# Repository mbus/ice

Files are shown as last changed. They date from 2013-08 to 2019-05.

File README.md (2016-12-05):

ICE EVM Board
=============

The ICE (In-Circuit Emulation) Evaluation Module is a debug board built for the
M3 ecosystem. In addition to acting as an M3 EVM, the ICE board can act as an
MBus debugger. ICE can act as a passive monitor, member node, or bus master as
desired.

ICE uses a [custom serial protocol][protocol] to communicate with a host PC.
There is a [Python library][py-ice] that provides a reasonably high-level API
to ICE and MBus.

This repository hosts the hardware and firmeware for ICE.

For more information, please visit http://mbus.io/ice.html

[protocol]: http://mbus.io/static/ICE-Protocol.pdf
[py-ice]: https://github.com/mbus/m3-python

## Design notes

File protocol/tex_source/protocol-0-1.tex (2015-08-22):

\subsection{Version 0.1}
\label{protocol-0-1}

\setcounter{tocdepth}{4}
\etocsettocstyle
    {\subsection*{\contentsname}\hrule\medskip
        \everypar{\rightskip.1\linewidth}}
    {\nobreak\medskip\hrule\bigskip}

\localtableofcontents

\subsubsection{\texttt{0x64 `d'} -- Discrete interface I2C message}
{\em Synchronous Request, Asynchronous Message}
\begin{itemize}
  \item[]
    \begin{bytefield}{40}
      \colorbitbox{lightgreen}{8}{`d'} &
      \colorbitbox{lightred}{8}{Event ID} &
      \colorbitbox{lightcyan}{8}{Length} &
      \bitbox{4}{Data...}
    \end{bytefield}
  \item The bytes in this message compose an I2C transaction.
  \item The length field of this message necessarily limits the maximum
    message size to 255 bytes (addr + 254 data). Longer messages should
    be fragmented.
  \item The sentinel value {\tt 255} for length indicates a {\em
    fragmented} message.
  \item[]
    \begin{itemize}
      \item A message fragment {\bf MUST} be exactly 255 bytes long.
      \item A fragment message {\bf MUST} be followed by another
        fragment, or terminated by a regular {\bf d}iscrete message.
        \begin{itemize}
          \item The ICE board is permitted to interleave other,
            non-I2C related messages (e.g. GPIO events).
        \end{itemize}
      \item A series of message fragments {\bf MUST} always be
        terminated by a discrete with an explicit length. An I2C transaction of
        length 0 is permitted, e.g.:
        \begin{itemize}
          \item An I2C transaction of length 510 (1 byte addr + 509 bytes
            of data) would be {\bf three} messages. The first of length
            255 (addr + bytes 0-253), the second of length 255 (bytes
            254-508), and the third of length 0 (there is no more
            data, but the fragment series must be terminated).
        \end{itemize}
      \item Fragments are treated as one logical message, but individual I2C bus
        transactions, by an ICE board.  In practice this means:
        \begin{itemize}
          \item Each fragment message must be individually ACK'd by ICE.
            \begin{itemize}
              \item A NAK'd fragment message ends an I2C message.
              \item The NAK offset is relative to the current fragment, not
                the whole I2C transaction.
            \end{itemize}
          \item Only the first fragment includes the I2C address.
          \item A stop bit should {\bf NOT} be generated after a
            fragment, instead the I2C clock should be stretched until the
            next fragment has arrived.
        \end{itemize}
    \end{itemize}
  \item ICE will respond with an ACK once every byte from an individual `d'
    message has been ACK'd on the I2C bus.
  \item If a byte is NAK'd on the I2C bus, ICE will respond with a NAK message
    of length 1 indicating the index of the first NAK'd byte (e.g. if the
    address is NAK'd, it will return 0).
    \begin{itemize}
      \item[]
        \begin{bytefield}{32}
          \colorbitbox{lightgreen}{8}{NAK (0x01)} &
          \colorbitbox{lightred}{8}{Event ID} &
          \colorbitbox{lightcyan}{8}{Len (Must be 1)} &
          \bitbox{8}{Index of Byte NAK'd}
        \end{bytefield}
    \end{itemize}
\end{itemize}

\subsubsection{\texttt{0x49 `I'} -- Query I2C Configuration}
{\em Synchronous Request}
\begin{itemize}
  \item[]
    \begin{bytefield} \\
      \colorbitbox{lightgreen}{8}{0x49} &
      \colorbitbox{lightred}{8}{Event ID} &
      \colorbitbox{lightcyan}{8}{Len (Must be 1)} &
      \colorbitbox{lightergreen}{8}{Parameter} &
    \end{bytefield}
  \item These messages complement the set I2C messages.
  \item The `Parameter' field is the parameter specifier to query.
  \item An ACK response should mimic the corresponding set message.
  \item The following would query/response the address mask:
    \begin{quote}
      \begin{bytefield} \\
        \colorbitbox{lightgreen}{8}{0x49} &
        \colorbitbox{lightred}{8}{Event ID} &
        \colorbitbox{lightcyan}{8}{0x01} &
        \colorbitbox{lightergreen}{8}{0x61} &
      \end{bytefield}

      \begin{bytefield} \\
        \colorbitbox{lightgreen}{8}{ACK (0x00)} &
        \colorbitbox{lightred}{8}{Event ID} &
        \colorbitbox{lightcyan}{8}{0x02} &
        \bitbox{8}{Ones Mask} &
        \bitbox{8}{Zeros Mask} &
      \end{bytefield}
    \end{quote}
\end{itemize}

\subsubsection{\texttt{0x69 `i'} -- Set I2C Configuration}
{\em Synchronous Request}
\begin{itemize}
  \item The first byte of the message shall define which parameter is to
    be configured.

  \paragraph{\texttt{0x69 0x63 `ic'} -- Set I2C Clock Speed}
    \begin{itemize}
      \item[]
        \begin{bytefield} \\
          \colorbitbox{lightgreen}{8}{`i'} &
          \colorbitbox{lightred}{8}{Event ID} &
          \colorbitbox{lightcyan}{8}{Len (Must be 2)} &
          \colorbitbox{lightergreen}{8}{`c'} &
          \bitbox{8}{Clock Speed}
        \end{bytefield}
      \item {\bf Default:} {\tt 0x32} (50, 100~kHz)
      \item This shall be followed by a single byte
        valued N, where N~*~2~kHz yeilds the desired clock speed. Values of N
        greater than 200 (400~kHz) exceed the I2C spec and may be rejected.
    \end{itemize}
  \paragraph{\texttt{0x69 0x61 `ia'} -- Set ICE I2C Address}
    \begin{itemize}
      \item[]
        \begin{bytefield} \\
          \colorbitbox{lightgreen}{8}{`i'} &
          \colorbitbox{lightred}{8}{Event ID} &
          \colorbitbox{lightcyan}{8}{Len (Must be 3)} &
          \colorbitbox{lightergreen}{8}{`a'} &
          \bitbox{8}{Ones Mask} &
          \bitbox{8}{Zeros Mask}
        \end{bytefield}
      \item {\bf Default:} {\tt 0xff 0xff} (disabled)
      \item This shall be followed by two bytes,
        first the {\em ones mask} and then the {\em zeroes mask} as outlined below.
        The command sets the address mask that ICE board should pretend to be a device
        for. Coneceptually the mask is of the form {\tt 10xx010x}, where x's signify
        don't care. This is conveyed as a {\em ones mask} and a {\em zeroes mask},
        where each mask defines the bits that must be a one or zero respectively. For
        the given example, the ones mask would be {\tt 10000100} and the zeroes mask
        {\tt 01001010}, generating a transaction of \mbox{\tt 0x61 0x84 0x4a}.
      \item To disable address-faking, set any bit
        as both required-one and required-zero. This impossible situation is a legal
        setting that will never match.
        \begin{itemize}
          \item {\em Note:} While it is
            permissable to set the last bit must-be-zero (writeable-only) or must-be-one
            (readable-only), it is almost certainly an error to do so.
        \end{itemize}
    \end{itemize}
  \paragraph{\texttt{0x69} Responses}
    \begin{itemize}
      \item NAKs for this message shall be composed of an error
        code, followed by an optional explanitory string.
        \begin{itemize}
          \item[]
            \begin{bytefield} \\
              \colorbitbox{lightgreen}{8}{NAK (0x01)} &
              \colorbitbox{lightred}{8}{Event ID} &
              \colorbitbox{lightcyan}{8}{Len (Min: 1)} &
              \colorbitbox{lightblue}{8}{EINVAL (0x16)} &
              \bitbox{8}{[{\tt "Out of Range"}]} &
            \end{bytefield}
          \item {\texttt {\textbf EINVAL (22,0x16):}} Invalid argument.
          \item[]
            \begin{bytefield} \\
              \colorbitbox{lightgreen}{8}{NAK (0x01)} &
              \colorbitbox{lightred}{8}{Event ID} &
              \colorbitbox{lightcyan}{8}{Len (Min: 1)} &
              \colorbitbox{lightblue}{8}{ENODEV (0x13)} &
            \end{bytefield}
          \item {\texttt {\textbf ENODEV (19,0x13):}} The
            implementation does not support changing or querying this parameter. Unless
            otherwise specified, it {\bf MUST} be hardcoded to the default.
        \end{itemize}
    \end{itemize}
\end{itemize}

\subsubsection{\texttt{0x66 `f'} -- FLOW (GOC) interface message}
{\em Synchronous Request}
\begin{itemize}
  \item FLOW messages are formatted the exact same as `d'iscrete messages.
\end{itemize}

\subsubsection{\texttt{0x4f `O'} -- Query optical (FLOW (GOC)) Configuration}
{\em Synchronous Request}
\begin{itemize}
  \item[]
    \begin{bytefield} \\
      \colorbitbox{lightgreen}{8}{`O' (0x4f)} &
      \colorbitbox{lightred}{8}{Event ID} &
      \colorbitbox{lightcyan}{8}{Len (Must be 1)} &
      \colorbitbox{lightergreen}{8}{Parameter} &
    \end{bytefield}
  \item These messages complement the set I2C messages.
  \item The `Parameter' field is the parameter specifier to query.
  \item An ACK response should mimic the corresponding set message.
\end{itemize}

\subsubsection{\texttt{0x6f `o'} -- Set optical (FLOW (GOC)) Configuration}
{\em Synchronous Request}
\begin{itemize}
  \item The first byte of the message shall define which parameter is to
    be configured.
    \paragraph{\texttt{0x6f 0x63 `oc'}: Clock Speed (Divider)}
      \begin{itemize}
        \item[]
          \begin{bytefield} \\
            \colorbitbox{lightgreen}{8}{`o'} &
            \colorbitbox{lightred}{8}{Event ID} &
            \colorbitbox{lightcyan}{8}{Len (Must be 4)} &
            \colorbitbox{lightergreen}{8}{`c'} &
            \bitbox{8}{Clock Divider}
          \end{bytefield}
        \item {\bf Default:} {\tt 0x30D400} (2~MHz / 0x30D400 = .625~Hz)
        \item This shall be followed by a three byte
          value N (MSB-first), where 2~MHz / N yields the desired clock speed.
      \end{itemize}
  \paragraph{\texttt{0x6f} Responses}
    \begin{itemize}
      \item NAKs for this message shall be composed of an error
        code, followed by an optional explanitory string.
        \begin{itemize}
          \item[]
            \begin{bytefield} \\
              \colorbitbox{lightgreen}{8}{NAK (0x01)} &
              \colorbitbox{lightred}{8}{Event ID} &
              \colorbitbox{lightcyan}{8}{Len (Min: 1)} &
              \colorbitbox{lightblue}{8}{EINVAL (0x16)} &
              \bitbox{8}{[{\tt "Out of Range"}]} &
            \end{bytefield}
          \item {\texttt {\textbf EINVAL (22,0x16):}} Invalid argument.
        \end{itemize}
    \end{itemize}
\end{itemize}

\subsubsection{\texttt{0x47 `G'} -- Query GPIO State / Configuration}
{\em Synchronous Request}
\begin{itemize}
  \item[]
    \begin{bytefield} \\
      \colorbitbox{lightgreen}{8}{`G' (0x47)} &
      \colorbitbox{lightred}{8}{Event ID} &
      \colorbitbox{lightcyan}{8}{Len (Must be 2)} &
      \colorbitbox{lightergreen}{8}{Parameter} &
      \bitbox{8}{GPIO IDX}
    \end{bytefield}
  \item These messages complement the set GPIO (`g') messages.
  \item The `Parameter' field is the parameter specifier to query.
  \item An ACK response should mimic the corresponding set message.
\end{itemize}

\subsubsection{\texttt{0x67 `g'} -- Set / Configure GPIO}
{\em Synchronous Request, Asynchronous Message}
\begin{itemize}
  \item The first byte of this message shall be a specificer, indicating
    what type of GPIO action is requested.
  \paragraph{\texttt{0x67 0x6c `gl'} -- GPIO Level}
    \begin{itemize}
      \item The first byte of the message shall be an integer
        indicating the GPIO index to set. The second byte shall be
        valued {\tt 0} or {\tt 1}, depending on the desired GPIO
        state.
      \item[]
        \begin{bytefield} \\
          \colorbitbox{lightgreen}{8}{`o' (0x67)} &
          \colorbitbox{lightred}{8}{Event ID} &
          \colorbitbox{lightcyan}{8}{Len (Must be 3)} &
          \colorbitbox{lightergreen}{8}{`l' (0x6c)} &
          \bitbox{8}{GPIO IDX} &
          \bitbox{8}{GPIO Val}
        \end{bytefield}
    \end{itemize}
  \paragraph{\texttt{0x67 0x64 `gd'} -- GPIO direction}
    \begin{itemize}
      \item The first byte of the message shall be an integer
        indicating the GPIO index to set the direction of. The second
        byte shall be valued:
        \begin{itemize}
          \item 0: Input
          \item 1: Output
          \item 2: TriState (\textsc{DEFAULT})
        \end{itemize}
      \item[]
        \begin{bytefield} \\
          \colorbitbox{lightgreen}{8}{`o' (0x67)} &
          \colorbitbox{lightred}{8}{Event ID} &
          \colorbitbox{lightcyan}{8}{Len (Must be 3))} &
          \colorbitbox{lightergreen}{8}{`d' (0x64)} &
          \bitbox{8}{GPIO IDX} &
          \bitbox{8}{GPIO Direction}
        \end{bytefield}
    \end{itemize}
  \paragraph{\texttt{0x67} Responses}
    \begin{itemize}
      \item {\texttt {\textbf ENODEV (19,0x13):}} The requested
        GPIO does not exist.
      \item[]
        \begin{bytefield} \\
          \colorbitbox{lightgreen}{8}{NAK (0x01)} &
          \colorbitbox{lightred}{8}{Event ID} &
          \colorbitbox{lightcyan}{8}{Len (Min: 1)} &
          \colorbitbox{lightblue}{8}{ENODEV (0x13)} &
          \bitbox{8}{[{\tt "No such GPIO"}]} &
        \end{bytefield}
      \item {\texttt {\textbf EINVAL (22,0x16):}} The requested GPIO
        exists, but cannot be configured this way at this time.
      \item[]
        \begin{bytefield} \\
          \colorbitbox{lightgreen}{8}{NAK (0x01)} &
          \colorbitbox{lightred}{8}{Event ID} &
          \colorbitbox{lightcyan}{8}{Len (Min: 1)} &
          \colorbitbox{lightblue}{8}{EINVAL (0x16)} &
          \bitbox{8}{[{\tt "GPIO is input"}]} &
        \end{bytefield}
    \end{itemize}
\end{itemize}

\subsubsection{\texttt{0x50 `P'} -- Query Power State}
{\em Synchronous Request}
\begin{itemize}
  \item[]
    \begin{bytefield} \\
      \colorbitbox{lightgreen}{8}{`P' (0x50)} &
      \colorbitbox{lightred}{8}{Event ID} &
      \colorbitbox{lightcyan}{8}{Len (Must be 1)} &
      \colorbitbox{lightergreen}{8}{Parameter} &
      \bitbox{8}{PWR IDX}
    \end{bytefield}
  \item These messages complement the Set Power (`p') messages.
  \item The `Parameter' field is the parameter specifier to query.
  \item An ACK response should mimic the corresponding set message.
\end{itemize}

\subsubsection{\texttt{0x70 `p'} -- Set Power State}
{\em Synchronous Request, Asynchronous Message}
\begin{itemize}
  \item Set Power State messages allow direct control of set-point voltage and on/off states for various power domains on the ICE board.  The first byte of this message shall be a specificer, indicating which parameter is requested.  The second byte of the message shall be the power domain identifier.  Currently implemented power domain identifiers are:
   \begin{itemize}
     \item 0: M3 0.6V (0.675V Default)
     \item 1: M3 1.2V (1.2V Default)
     \item 2: M3 VBatt (3.8V Default)
   \end{itemize}
  \paragraph{\texttt{0x70 0x76 `pv'} -- Voltage State}
    \begin{itemize}
      \item The first byte of the message shall be a single byte indicating the power domain identifier to set.  The second byte ($v\_set$) shall specify the voltage according to the equation:
$$V_{out} = (0.537 + 0.0185*v\_set)*V_{default}$$
      Valid values for $v\_set$ range from {\tt 0} to {\tt 31}
      \item[]
        \begin{bytefield} \\
          \colorbitbox{lightgreen}{8}{`p' (0x70)} &
          \colorbitbox{lightred}{8}{Event ID} &
          \colorbitbox{lightcyan}{8}{Len (Must be 3)} &
          \colorbitbox{lightergreen}{8}{`v' (0x76)} &
          \bitbox{8}{PWR IDX} &
          \bitbox{8}{$v\_set$}
        \end{bytefield}
    \end{itemize}
  \paragraph{\texttt{0x70 0x6f `po'} -- On/Off State}
    \begin{itemize}
      \item The first byte of the message shall be a single byte indicating the power domain identifier to set.  The second byte shall be
        valued {\tt 0} or {\tt 1}, depending on the desired On/Off
        state.
      \item[]
        \begin{bytefield} \\
          \colorbitbox{lightgreen}{8}{`p' (0x70)} &
          \colorbitbox{lightred}{8}{Event ID} &
          \colorbitbox{lightcyan}{8}{Len (Must be 3)} &
          \colorbitbox{lightergreen}{8}{`o' (0x6f)} &
          \bitbox{8}{PWR IDX} &
          \bitbox{8}{On/Off}
        \end{bytefield}
    \end{itemize}
\end{itemize}

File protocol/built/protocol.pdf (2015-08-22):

# ICE Debug Board FPGA Interface protocol

Ben Kempke, Pat Pannuto {bpkempke,ppannuto}@umich.edu

Revision 0.2.6 — October 17, 2013

## Introduction

The ICE board is a dual-purpose development board, enabling both high-speed programming (via DMA) of M3 chips and interfacing with live M3 sessions and external peripherals.
This means that libraries must be able to gracefully handle asychronous, unexpected events. In particular, some semantics resemebling transactions would be desirable, as well as an effort to maintain event ordering over the serial communications link. The consequence is that this document should be viewed less as a protocol specification and more of a living document as we explore the best semantics for this domain.
At a high-level, every message is a composition of an event id, a message type and an optional message. Every message sent to the ICE board MUST be replied to by either an ACK or NAK response. Every message sent from the ICE board MUST NOT be acknowledged. The rationale for this asymmetry is to simplify the ICE hardware design. With this mechanism, the hardware is not obligated to preserve any communication state beyond the immediate running context. The event ids provide a total ordering of the event history, insofar as is possible.

## Contents

1 Event Ids | 2
2 Messages / Base Protocol | 3
3 Protocols | 5
4 Document Revision History | 30
Revision 0.2.6 – Oct 17, 2013 | 1

1 EVENT IDS

## 1 Event Ids

### 1.1 Motivation

Some decisions in microcontrollers necessarily race. As contrived example, if two GPIO pins are defined as interrupts but are electrically connected in the external circuit, and then line is pulled high, which interrupt fires first? While the decision is arbitrary, there is motivation to define an ordering of events in the system. The events observed by ICE can be replayed in the M-ultaor fi.

2 MESSAGES / BASE PROTOCOL

## 2 Messages / Base Protocol

Messages are composed of a one-byte message type identifier followed by a one-byte event identifier followed by a one-byte unsigned length indicator followed by an optional message component. Visually:

Message Type | Event ID | Length | [Message Data...]

Effort should be made to keep type identifiers within the ASCII range where reasonable, mapped to appropriate letters.
There are two types of transactions defined: synchronous and asynchronous. A synchronous message is one initiated by the controlling PC and must be responded to by a {N}ACK from the ICE board. An asychronous message is generated by the ICE board in response to a hardware event. Only one synchronous message is permitted to be live at any given time. The ICE board may send any number of asychronous messages before responding to the synchronous message.
The protocol in use is undefined until a version request is ACKed. The reception of a NAK with reason with a preferred version is NOT sufficient to establish a version, the controller MUST explicilty send another version request and receive an ACK to establish the protocol version in use.
Only ‘V’ and ‘v’ messages are valid until a version has been negotiated. Any asynchronous hardware events may either be queued or discarded.

The base protocol defines the following immutable message types and their properties:

0x00 ACK

0x01 NAK

Synchronous Response

0x00 or 0x01 | Event ID | Len (Min: 0) | [Data...]
- 0: ACK. Indicates success.
- 1: NAK. Generic error code indicating failure.

– Unless otherwise specified...
- The remaining bytes shall be an ASCII-encoded string composed only of standard printable characters. The string shall not be NUL-terminated. The contents of this string is not well-defined and is expected to be something human-readable and useful.
– If specified...
- The response is permitted to be implementation defined.

0x56 (‘V’) – Query Versions

Synchronous Request

0x56 | Event ID | Len (Must be 0)

– This message queries the protocol version(s) this ICE implementation understands.

– If multiple versions are supported, they should be listed in order of version preference.

– Response:

0x00 | Event ID | Len (Min: 2) | Major | Minor | [Major...] | [Minor...]

0x76 (‘v’) – Request to use version

Synchronous Request

0x76 | Event ID | Len (Must be 2) | Major | Minor

2 MESSAGES / BASE PROTOCOL

– The message shall be composed of exactly two bytes.

– Each byte shall be an unsigned number.

– The first byte shall be considered a major version number.

– The second byte shall be considered a minor version number.

– Response:

0x00 | Event ID | Len (Must be 0)
- If the selected version is acceptable, an ACK shall be generated.
0x01 | Event ID | Length | [Major] | [Minor]
- Otherwise a NAK shall be generated.
- The NAK may optionally include a preferred version or list of versions in the same format as the ‘V’ response.

– This message is not queriable.

0x58 (‘X’) – eXtension

0x78 (‘x’) – extension

– These characters are reserved for future eXtentions.

– No further specification is defined here.

3 PROTOCOLS

## 3 Protocols

The following protocols are currently well-defined:

Contents

3.1 Version 0.1 | 3 PROTOCOLS

### 3.1 Version 0.1

Contents

3.1.1 0x64 ‘d’ – Discrete interface I2C message

Synchronous Request, Asynchronous Message

‘d’ | Event ID | Length | Data...

The bytes in this message compose an I2C transaction.

The length field of this message necessarily limits the maximum message size to 255 bytes (addr + 254 data). Longer messages should be fragmented.

The sentinel value 255 for length indicates a fragmented message.

– A message fragment MUST be exactly 255 bytes long.

– A fragment message MUST be followed by another fragment, or terminated by a regular discrete message.
- The ICE board is permitted to interleave other, non-I2C related messages (e.g. GPIO events).

– A series of message fragments MUST always be terminated by a discrete with an explicit length. An I2C transaction of length 0 is permitted, e.g.:
- An I2C transaction of length 510 (1 byte addr + 509 bytes of data) would be three messages. The first of length 255 (addr + bytes 0-253), the second of length 255 (bytes 254-508), and the third of length 0 (there is no more data, but the fragment series must be terminated).

– Fragments are treated as one logical message, but individual I2C bus transactions, by an ICE board. In practice this means:
- Each fragment message must be individually ACK’d by ICE.
→ A NAK’d fragment message ends an I2C message.
→ The NAK offset is relative to the current fragment, not the whole I2C transaction.
- Only the first fragment includes the I2C address.

3.1 Version 0.1 | 3 PROTOCOLS
- A stop bit should NOT be generated after a fragment, instead the I2C clock should be stretched until the next fragment has arrived.

ICE will respond with an ACK once every byte from an individual ‘d’ message has been ACK’d on the I2C bus.

If a byte is NAK’d on the I2C bus, ICE will respond with a NAK message of length 1 indicating the index of the first NAK’d byte (e.g. if the address is NAK’d, it will return 0).

NAK (0x01) | Event ID | Len (Must be 1) | Index of Byte
NAK’d

3.1.2 0x49 ‘I’ – Query I2C Configuration

Synchronous Request

0x49 | Event ID | Len (Must be 1) | Parameter

These messages complement the set I2C messages.

The ‘Parameter’ field is the parameter specifier to query.

An ACK response should mimic the corresponding set message.

The following would query/response the address mask:

0x49 | Event ID | 0x01 | 0x61
ACK (0x00) | Event ID | 0x02 | Ones Mask | Zeros Mask

3.1.3 0x69 ‘i’ – Set I2C Configuration

Synchronous Request

The first byte of the message shall define which parameter is to be configured.

0x69 0x63 ‘ic’ – Set I2C Clock Speed

‘i’ | Event ID | Len (Must be 2) | ‘c’ | Clock Speed

– Default: 0x32 (50, 100 kHz)
– This shall be followed by a single byte valued N, where N * 2 kHz yeilds the desired clock speed. Values of N greater than 200 (400 kHz) exceed the I2C spec and may be rejected.

0x69 0x61 ‘ia’ – Set ICE I2C Address

‘i’ | Event ID | Len (Must be 3) | ‘a’ | Ones Mask | Zeros Mask

– Default: 0xff 0xff (disabled)
– This shall be followed by two bytes, first the ones mask and then the zeroes mask as outlined below. The command sets the address mask that ICE board should pretend to be a device for. Coneceptually the mask is of the form 10xx010x, where x’s signify don’t care. This is conveyed as a ones mask and a zeroes mask, where each mask defines the bits that must be a one or zero respectively. For the given example, the ones mask would be 10000100 and the zeroes mask 01001010, generating a transaction of 0x61 0x84 0x4a.
– To disable address-faking, set any bit as both required-one and required-zero. This impossible situation is a legal setting that will never match.
- Note: While it is permissable to set the last bit must-be-zero (writeable-only) or must-be-one (readable-only), it is almost certainly an error to do so.

3.1 Version 0.1 | 3 PROTOCOLS

0x69 Responses

– NAKs for this message shall be composed of an error code, followed by an optional explanitory string.

NAK (0x01) | Event ID | Len (Min: 1) | EINVAL (0x16) | ["Out of Range"]
- EINVAL (22,0x16): Invalid argument.
NAK (0x01) | Event ID | Len (Min: 1) | ENODEV (0x13)
- ENODEV (19,0x13): The implementation does not support changing or querying this parameter. Unless otherwise specified, it MUST be hardcoded to the default.

3.1.4 0x66 ‘f’ – FLOW (GOC) interface message

Synchronous Request

FLOW messages are formatted the exact same as ‘d’iscrete messages.

3.1.5 0x4f ‘O’ – Query optical (FLOW (GOC)) Configuration

Synchronous Request

‘O’ (0x4f) | Event ID | Len (Must be 1) | Parameter

These messages complement the set I2C messages.

The ‘Parameter’ field is the parameter specifier to query.

An ACK response should mimic the corresponding set message.

3.1.6 0x6f ‘o’ – Set optical (FLOW (GOC)) Configuration

Synchronous Request

The first byte of the message shall define which parameter is to be configured.

0x6f 0x63 ‘oc’: Clock Speed (Divider)

‘o’ | Event ID | Len (Must be 4) | ‘c’ | Clock Divider

– Default: 0x30D400 (2 MHz / 0x30D400 = .625 Hz)

– This shall be followed by a three byte value N (MSB-first), where 2 MHz / N yields the desired clock speed.

0x6f Responses

– NAKs for this message shall be composed of an error code, followed by an optional explanitory string.

NAK (0x01) | Event ID | Len (Min: 1) | EINVAL (0x16) | ["Out of Range"]
- EINVAL (22,0x16): Invalid argument.

3.1 Version 0.1 | 3 PROTOCOLS

3.1.7 0x47 ‘G’ – Query GPIO State / Configuration

Synchronous Request

‘G’ (0x47) | Event ID | Len (Must be 2) | Parameter | GPIO IDX

These messages complement the set GPIO (‘g’) messages.

The ‘Parameter’ field is the parameter specifier to query.

An ACK response should mimic the corresponding set message.

3.1.8 0x67 ‘g’ – Set / Configure GPIO

Synchronous Request, Asynchronous Message

The first byte of this message shall be a specificer, indicating what type of GPIO action is requested.

0x67 0x6c ‘gl’ – GPIO Level

– The first byte of the message shall be an integer indicating the GPIO index to set. The second byte shall be valued 0 or 1, depending on the desired GPIO state.

‘o’ (0x67) | Event ID | Len (Must be 3) | ‘l’ (0x6c) | GPIO IDX | GPIO Val

0x67 0x64 ‘gd’ – GPIO direction

– The first byte of the message shall be an integer indicating the GPIO index to set the direction of. The second byte shall be valued:
- 0: Input
- 1: Output
- 2: TriState (DEFAULT)
‘o’ (0x67) | Event ID | Len (Must be 3)) | ‘d’ (0x64) | GPIO IDX | GPIO Direction

0x67 Responses

– ENODEV (19,0x13): The requested GPIO does not exist.

NAK (0x01) | Event ID | Len (Min: 1) | ENODEV (0x13) | ["No such GPIO"]

– EINVAL (22,0x16): The requested GPIO exists, but cannot be configured this way at this time.

NAK (0x01) | Event ID | Len (Min: 1) | EINVAL (0x16) | ["GPIO is input"]

3.1.9 0x50 ‘P’ – Query Power State

Synchronous Request

‘P’ (0x50) | Event ID | Len (Must be 1) | Parameter | PWR IDX

These messages complement the Set Power (‘p’) messages.

The ‘Parameter’ field is the parameter specifier to query.

An ACK response should mimic the corresponding set message.

3.1 Version 0.1 | 3 PROTOCOLS

3.1.10 0x70 ‘p’ – Set Power State

Synchronous Request, Asynchronous Message

Set Power State messages allow direct control of set-point voltage and on/off states for various power domains on the ICE board. The first byte of this message shall be a specificer, indicating which parameter is requested. The second byte of the message shall be the power domain identifier. Currently implemented power domain identifiers are:

– 0: M3 0.6V (0.675V Default)

– 1: M3 1.2V (1.2V Default)

– 2: M3 VBatt (3.8V Default)

0x70 0x76 ‘pv’ – Voltage State

– The first byte of the message shall be a single byte indicating the power domain identifier to set. The second byte (v set) shall specify the voltage according to the equation:

Vout = (0.537 + 0.0185 ∗ v set) ∗ Vdefault

Valid values for v set range from 0 to 31

‘p’ (0x70) | Event ID | Len (Must be 3) | ‘v’ (0x76) | PWR IDX | v set

0x70 0x6f ‘po’ – On/Off State

– The first byte of the message shall be a single byte indicating the power domain identifier to set. The second byte shall be valued 0 or 1, depending on the desired On/Off state.

‘p’ (0x70) | Event ID | Len (Must be 3) | ‘o’ (0x6f) | PWR IDX | On/Off

3.2 Version 0.2 | 3 PROTOCOLS

### 3.2 Version 0.2

Version 0.2 adds the following new messages:

‘Oo’ and ‘oo’. These messages allow the default on/off state of the GOC light to be set.

‘??’. This message queries the capabilities of the ICE board.

‘?B’, ‘?b’. These messages get and set the ICE baud rate.

‘B’, ‘b’, ‘M’, and ‘m’. These messages control the MBus interface.

‘e’. This command injects messages on the EIN debug port.

Contents

3.2 Version 0.2 | 3 PROTOCOLS

3.2.1 0x3f ‘?’ – Query ICE

Synchronous Request

The first byte of this message shall be a specificer, indicating what type of query is requested.

0x3f 0x3f ‘??’ – Query capabilities

– This message shall query the capabilities of this ICE board. Not all boards have every hardware frontend. Use this message to query the capabilities of a given ICE board.

‘?’ (0x3f) | Event ID | Len (Must be 1) | ‘?’ (0x3f)

– This message shall be responded to with a list of all top-level identifiers that the ICE board is capable of acting usefully upon. That is, if the ICE firmware understands ‘d’ messages but does not have an I2C frontend ‘d’ shall be omitted. Sub-types are not specified by this command. That is, if a version 0.2 ICE includes ‘o’ in its response it is assumed to understand both the ‘oc’ and ‘oo’ messages.

– Both set and query commands should be included in this list. That is, if a GOC frontend is present, both ‘o’ and ‘O’ should be included.
– As example, a version 0.2 ICE with no physical I2C frontend would respond:
ACK (0x00) | Event ID | Len (11) | ‘? IifOoGgPp’ (0x3f5f4969664f6f47675070)

0x3f 0x62 ‘?b’ – Query baudrate

– This message shall mirror the ‘ b’ message and report the currently set baud rate.

0x3f Responses

– NAKs for this message shall be composed of an error code, followed by an optional explanatory string.

NAK (0x01) | Event ID | Len (Min: 1) | EINVAL (0x16) | ["Out of Range"]
- EINVAL (22,0x16): Invalid argument.

3.2.2 0x5f ‘ ’ – Configure ICE

Synchronous Request

The first byte of this message shall be a specificer, indicating what type of query is requested.

‘ ’ commands are setters for the ’?’ getters if appropriate.

3.2 Version 0.2 | 3 PROTOCOLS

0x5f 0x62 ‘ b’ – Set baudrate

‘ ’ | Event ID | Len (Must be 3) | ‘b’ | Clock Divider

– This message shall set the baud rate for future messages. The new baud rate shall take effect after the ACK for this request.
– This shall be followed by a two byte value N (MSB-first), where N = d
| | | | 20 MHz BaudRate e.

– Default: 0x00AE (20 MHz / 0x00AE ≈ 115200 Hz)

– The following message would set the ICE speed to 3 Megabaud:

‘ ’ (0x5f) | Event ID | Length (3) | ‘b’ (0x62) | 0x0007

3.2.3 0x64 ‘d’ – Discrete interface I2C message

Synchronous Request, Asynchronous Message

‘d’ | Event ID | Length | Data...

The bytes in this message compose an I2C transaction.

The length field of this message necessarily limits the maximum message size to 255 bytes (addr + 254 data). Longer messages should be fragmented.

The sentinel value 255 for length indicates a fragmented message.

– A message fragment MUST be exactly 255 bytes long.

– A fragment message MUST be followed by another fragment, or terminated by a regular discrete message.
- The ICE board is permitted to interleave other, non-I2C related messages (e.g. GPIO events).

– A series of message fragments MUST always be terminated by a discrete with an explicit length. An I2C transaction of length 0 is permitted, e.g.:
- An I2C transaction of length 510 (1 byte addr + 509 bytes of data) would be three messages. The first of length 255 (addr + bytes 0-253), the second of length 255 (bytes 254-508), and the third of length 0 (there is no more data, but the fragment series must be terminated).

– Fragments are treated as one logical message, but individual I2C bus transactions, by an ICE board. In practice this means:
- Each fragment message must be individually ACK’d by ICE.
→ A NAK’d fragment message ends an I2C message.
→ The NAK offset is relative to the current fragment, not the whole I2C transaction.
- Only the first fragment includes the I2C address.
- A stop bit should NOT be generated after a fragment, instead the I2C clock should be stretched until the next fragment has arrived.

ICE will respond with an ACK once every byte from an individual ‘d’ message has been ACK’d on the I2C bus.

If a byte is NAK’d on the I2C bus, ICE will respond with a NAK message of length 1 indicating the index of the first NAK’d byte (e.g. if the address is NAK’d, it will return 0).

NAK (0x01) | Event ID | Len (Must be 1) | Index of Byte NAK’d

3.2 Version 0.2 | 3 PROTOCOLS

3.2.4 0x49 ‘I’ – Query I2C Configuration

Synchronous Request

0x49 | Event ID | Length | Parameter

These messages complement the set I2C messages.

The ‘Parameter’ field is the parameter specifier to query.

An ACK response should mimic the corresponding set message.

The following would query/response the address mask:

0x49 | Event ID | 0x01 | 0x61
ACK (0x00) | Event ID | 0x02 | Ones Mask | Zeros Mask

3.2.5 0x69 ‘i’ – Set I2C Configuration

Synchronous Request

The first byte of the message shall define which parameter is to be configured.

0x69 0x63 ‘ic’ – Set I2C Clock Speed

‘i’ | Event ID | Len (Must be 2) | ‘c’ | Clock Speed

– Default: 0x32 (50, 100 kHz)

– This shall be followed by a single byte valued N, where N * 2 kHz yeilds the desired clock speed. Values of N greater than 200 (400 kHz) exceed the I2C spec and may be rejected.

0x69 0x61 ‘ia’ – Set ICE I2C Address

‘i’ | Event ID | Len (Must be 3) | ‘a’ | Ones Mask | Zeros Mask

– Default: 0xff 0xff (disabled)

– This shall be followed by two bytes, first the ones mask and then the zeroes mask as outlined below. The command sets the address mask that ICE board should pretend to be a device for. Coneceptually the mask is of the form 10xx010x, where x’s signify don’t care. This is conveyed as a ones mask and a zeroes mask, where each mask defines the bits that must be a one or zero respectively. For the given example, the ones mask would be 10000100 and the zeroes mask 01001010, generating a transaction of 0x61 0x84 0x4a.

– To disable address-faking, set any bit as both required-one and required-zero. This impossible situation is a legal setting that will never match.
- Note: While it is permissable to set the last bit must-be-zero (writeable-only) or must-be-one (readable-only), it is almost certainly an error to do so.

3.2 Version 0.2 | 3 PROTOCOLS

0x69 Responses

– NAKs for this message shall be composed of an error code, followed by an optional explanitory string.

NAK (0x01) | Event ID | Len (Min: 1) | EINVAL (0x16) | ["Out of Range"]
- EINVAL (22,0x16): Invalid argument.
NAK (0x01) | Event ID | Len (Min: 1) | ENODEV (0x13)
- ENODEV (19,0x13): The implementation does not support changing or querying this parameter. Unless otherwise specified, it MUST be hardcoded to the default.

3.2.6 0x66 ‘f’ – Debug (GOC/EIN) interface message

Synchronous Request

Debug interface messages are formatted the exact same as ‘d’iscrete messages.

3.2.7 0x4f ‘O’ – Query debug (GOC/EIN) Configuration

Synchronous Request

‘O’ (0x4f) | Event ID | Len (Must be 1) | Parameter

These messages complement the set ‘o’ messages.

The ‘Parameter’ field is the parameter specifier to query.

An ACK response should mimic the corresponding set message.

3.2.8 0x6f ‘o’ – Set debug (GOC/EIN) Configuration

Synchronous Request

The first byte of the message shall define which parameter is to be configured.

0x6f 0x63 ‘oc’: Clock Speed (Divider)

‘o’ | Event ID | Len (Must be 4) | ‘c’ | Clock Divider

– Default: 0x30D400 (2 MHz / 0x30D400 = .625 Hz)

– This shall be followed by a three byte value N (MSB-first), where 2 MHz / N yields the desired clock speed.

0x6f 0x70 ‘op’: Debug mode

‘o’ | Event ID | Len (Must be 2) | ‘p’ | GOC / EIN

– Default: 0x0 (EIN)

– Specifies which interface to use when transferring debug data. Possible values:

0 EIN
1 GOC

3.2 Version 0.2 | 3 PROTOCOLS

0x6f 0x6f ‘oo’: GOC light On/Off

‘o’ | Event ID | Len (Must be 2) | ‘o’ | On / Off

– Default: 0x0 (Off)
– This shall be followed by either a 0 or a 1 indicating whether the default state of the light should be on or off. If the default is set to on, the light shall remain illuminated until set to off or a GOC pulse temporarily turns if off.

0x6f Responses

– NAKs for this message shall be composed of an error code, followed by an optional explanatory string.

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

3.2.9 0x42 ‘B’ – MBus Snooped Message

Asynchronous Message

‘B’ | Event ID | Len (Min: 5) | MBus Address | MBus Data | MBus Control

This shall be followed by a 32-bit MBus destination address as well as optional data. The current MBus implementation operates on 4-byte words, so the data field length must be a multiple of four. As with discrete (‘d’) messages, the length field limits the maximum message size to 255 bytes. Longer messages should be fragmented.

At the end of the message, snoop messages shall append one additional byte. This additional byte shall indicate the control bits of the snooped message. Control Bit 0 shall be mapped to bit 0 and Control Bit 1 shall be mapped to bit 1. The remaining bits are undefined.

This message is sent only from the ICE board to report messages it has snooped (but not ACK’d).

Messages that match both the ICE address and the snoop address (that is, would generate both ‘b’ and ‘B’ messages) shall not report snoop messages.

The ICE board shall not report snoop messages for message that it is sending.

3.2.10 0x62 ‘b’ – MBus Message

Synchronous Request, Asynchronous Message

MBus messages are formatted the exact same as ‘MBus Snooped’ (‘B’) messages.

This command may be sent to the ICE board to send a message.

This message is sent from the ICE board to report messages sent to ICE. That is messages that matched the address masks assigned to ICE and that ICE has ACK’d on the bus.

3.2.11 0x4d ‘M’ – Query MBus Configuration

Synchronous Request

‘M’ (0x4d) | Event ID | Length | Parameter

These messages complement the set of ‘m’ messages.

The ‘Parameter’ field is the parameter specifier to query.

An ACK response should mimic the corresponding set message.

3.2 Version 0.2 | 3 PROTOCOLS

3.2.12 0x6d ‘m’ – Set MBus Configuration

Synchronous Request

The first byte of the message shall define which parameter is to be configured.

0x6d 0x6c ‘ml’: Set MBus Full Prefix

‘m’ | Event ID | Len (Must be 7) | ‘l’ | Ones Mask | Zeros Mask

– Default: 0xfffff0 0xfffff0 (Disabled)

– NOTE: This command is not supported by the current MBus implementation.

– This shall be followed by 6 bytes. The first three bytes shall be considered the ones mask the second three bytes shall be considered the zeros mask. The masks are 20 bits long, the bottom 4 bits of the transmitted masks shall be ignored.

0x6d 0x73 ‘ms’: Set MBus Short Prefix

‘m’ | Event ID | Len (Must be 3) | ‘s’ | Ones Mask | Zeros Mask

– Default: 0xf0 0xf0 (Disabled)

– NOTE: This command is not supported by the current MBus implementation.

– This shall be followed by 2 bytes. The first byte shall be considered the ones mask the second byte shall be considered the zeros mask. The masks are 4 bits long, the bottom 4 bits of the transmitted masks shall be ignored.

– NOTE: Changing the short prefix after enumeration is a violation of the MBus protocol. The ICE board will permit this, but it may have unexpected consequences.

0x6d 0x4c ‘mL’: Set MBus Snoop Full Prefix

‘m’ | Event ID | Len (Must be 7) | ‘L’ | Ones Mask | Zeros Mask

– Default: 0xfffff0 0xfffff0 (Disabled)

– NOTE: This command is not supported by the current MBus implementation.

– This shall be followed by 6 bytes. The first three bytes shall be considered the ones mask the second three bytes shall be considered the zeros mask. The masks are 20 bits long, the bottom 4 bits of the transmitted masks shall be ignored.

– Messages matching the snoop prefix shall be reported by a ‘B’ message but will not be ACK’d on the physical bus by ICE.

– In the case of a conflict between a snoop and a match, the match takes precedence and ICE will ACK the message.

0x6d 0x53 ‘mS’: Set MBus Snoop Short Prefix

‘m’ | Event ID | Len (Must be 3) | ‘S’ | Ones Mask | Zeros Mask

– Default: 0xf0 0xf0 (Disabled)

– NOTE: This command is not supported by the current MBus implementation.

– This shall be followed by 2 bytes. The first byte shall be considered the ones mask the second byte shall be considered the zeros mask. The masks are 4 bits long, the bottom 4 bits of the transmitted masks shall be ignored.

3.2 Version 0.2 | 3 PROTOCOLS

– Messages matching the snoop prefix shall be reported by a ‘B’ message but will not be ACK’d on the physical bus by ICE.

– In the case of a conflict between a snoop and a match, the match takes precedence and ICE will ACK the message.

0x6d 0x73 ‘mb’: Set MBus Broadcast Mask

‘m’ | Event ID | Len (Must be 1) | ‘b’ | Ones Mask | Zeros Mask

– Default: 0x0f 0x0f (Disabled)

– NOTE: This command is not supported by the current MBus implementation.

– This shall be followed by 2 bytes. The first byte shall be considered the ones mask the second byte shall be considered the zeros mask. The masks are 4 bits long, the top 4 bits of the transmitted masks shall be ignored.
– These masks are the set of broadcast channels that the ICE board should ACK on the physical MBus.

0x6d 0x53 ‘mB’: Set MBus Snoop Broadcast Mask

‘m’ | Event ID | Len (Must be 1) | ‘B’ | Ones Mask | Zeros Mask

– Default: 0x0f 0x0f (Disabled)

– NOTE: This command is not supported by the current MBus implementation.

– This shall be followed by 2 bytes. The first byte shall be considered the ones mask the second byte shall be considered the zeros mask. The masks are 4 bits long, the top 4 bits of the transmitted masks shall be ignored.
– These masks are the set of broadcast channels that the ICE board will not ACK on the physical MBus but will report as a snooped message (a ‘B’ message).

– In the case of a conflict between a snoop and a match, the match takes precedence and ICE will ACK the message.

0x6d 0x6d ‘mm’: Set master mode on/off

‘m’ | Event ID | Len (Must be 2) | ‘m’ | 0x00 or 0x01

– Default: 0x0 (Off)

– Boolean whether ICE should act as the MBus master node (1 - on) or as a MBus member node (0 - off).

0x6d 0x63 ‘mc’: Clock Speed

‘o’ | Event ID | Len (4) | ‘c’ | Clock Divider

– Default: 0x000020 (10 MHz / 0x000020 = 312.5 kHz)

– This shall be followed by a three byte value N (MSB-first), where 10 MHz / N yields the desired clock speed.
– This configuration is meaningful only if ICE is configured as the MBus master node (see ‘mm’).

3.2 Version 0.2 | 3 PROTOCOLS

0x6d 0x69 ‘mi’: Set should interrupt

‘m’ | Event ID | Len (Must be 2) | ‘i’ | SHOULD INT

– Default: 0x0 (Off)

– NOTE: This command is not supported by the current MBus implementation.

– Configures whether ICE should interrupt the bus to transmit its next message. Possible values:

0 Do not interrupt
1 Interrupt (if necessary) for next message only. That is, this value is reset to 0 after the next ‘b’ command sent to ICE is handled.
2 Interrupt for all messages

0x6d 0x70 ‘mp’: Set should use priority arbitration

‘m’ | Event ID | Len (Must be 2) | ‘p’ | SHOULD PRIO

– Default: 0x0 (Off)

– Configures whether ICE should send high priority MBus messages. Possible values:

0 Do not send priority message.
1 Send all messages as high priority.

0x6d Responses

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

NAK (0x01) | Event ID | Len (Min: 1) | EINVAL (0x16) | ["Out of Range"]
- EINVAL (22,0x16): Invalid argument.
NAK (0x01) | Event ID | Len (Min: 1) | ENODEV (0x13)
- ENODEV (19,0x13): The implementation does not support changing or querying this parameter. Unless otherwise specified, it MUST be hardcoded to the default.

3.2.13 0x47 ‘G’ – Query GPIO State / Configuration

Synchronous Request

‘G’ (0x47) | Event ID | Len (Must be 1) | GPIO IDX

These messages complement the set GPIO (‘g’) messages.

An ACK response should mimic the corresponding set message.

3.2.14 0x67 ‘g’ – Set / Configure GPIO

Synchronous Request, Asynchronous Message

The first byte of this message shall be a specificer, indicating what type of GPIO action is requested.

3.2 Version 0.2 | 3 PROTOCOLS

0x67 0x6c ‘gl’ – GPIO Level

‘o’ (0x67) | Event ID | Len (Must be 4) | ‘l’ (0x6c) | GPIO Mask

– Default: 0x000000 (All low)
– This shall be followed by a three byte bitmask indicating the desired output level of all 24 GPIO. This is only reflected in those GPIO which are configured as output. Each bit shall be valued:
- 0: Low (0.0 V)
- 1: High (1.2 V)

0x67 0x64 ‘gd’ – GPIO Direction

‘o’ (0x67) | Event ID | Len (Must be 4)) | ‘d’ (0x64) | GPIO Mask

– Default: 0x000000 (All input)
– This shall be followed by a three byte bitmask indicating the desired direction of all 24 GPIO. The output level of each GPIO which are configured as output are set via the ‘Set GPIO Level’ (‘gl’) command. Each bit shall be valued:
- 0: Input (DEFAULT)
- 1: Output

0x67 0x69 ‘gi’ – GPIO Interrupt Enable

‘o’ (0x67) | Event ID | Len (Must be 4)) | ‘d’ (0x64) | GPIO Mask

– Default: 0x000000 (All interrupts disabled)
– This shall be followed by a three byte bitmask indicating whether a change in each GPIO bit wil generate an GPIO level change message. Only those GPIO which are configured as input will generate interrupts. Each bit shall be valued:
- 0: Interrupt Disabled (DEFAULT)
- 1: Interrupt Enabled

3.2.15 0x50 ‘P’ – Query Power State

Synchronous Request

‘P’ (0x50) | Event ID | Len (Must be 1) | Parameter | PWR IDX

These messages complement the Set Power (‘p’) messages.

The ‘Parameter’ field is the parameter specifier to query.

An ACK response should mimic the corresponding set message.

3.2.16 0x70 ‘p’ – Set Power State

Synchronous Request, Asynchronous Message

Set Power State messages allow direct control of set-point voltage and on/off states for various power domains on the ICE board. The first byte of this message shall be a specificer, indicating which parameter is requested. The second byte of the message shall be the power domain identifier. Currently implemented power domain identifiers are:

– 0: M3 0.6V (0.675V Default)
– 1: M3 1.2V (1.2V Default)
– 2: M3 VBatt (3.8V Default)

3.2 Version 0.2 | 3 PROTOCOLS

0x70 0x76 ‘pv’ – Voltage State

– The first byte of the message shall be a single byte indicating the power domain identifier to set. The second byte (v set) shall specify the voltage according to the equation:

Vout = (0.537 + 0.0185 ∗ v set) ∗ Vdefault

Valid values for v set range from 0 to 31

‘p’ (0x70) | Event ID | Len (Must be 3) | ‘v’ (0x76) | PWR IDX | v set

0x70 0x6f ‘po’ – On/Off State

– The first byte of the message shall be a single byte indicating the power domain identifier to set. The second byte shall be valued 0 or 1, depending on the desired On/Off state.

‘p’ (0x70) | Event ID | Len (Must be 3) | ‘o’ (0x6f) | PWR IDX | On/Off

3.3 Version 0.3 | 3 PROTOCOLS

### 3.3 Version 0.3

Version 0.3 modifies the following messages:

– ‘oc’: EIN Clock Divider – argument increased to 3 bytes to allow for slower GOC/EIN speeds.

– ‘p’: Set Power State – Additional voltage domain added for USB GOC light.

Version 0.3 deprecates support for the following messages:

– ‘d’: Discrete interface I2C message

– ‘I’: Query I2C Configuration

– ‘i’: Set I2C Configuration

Contents

3.3 Version 0.3 | 3 PROTOCOLS

3.3.1 0x3f ‘?’ – Query ICE

Synchronous Request

The first byte of this message shall be a specificer, indicating what type of query is requested.

0x3f 0x3f ‘??’ – Query capabilities

– This message shall query the capabilities of this ICE board. Not all boards have every hardware frontend. Use this message to query the capabilities of a given ICE board.

‘?’ (0x3f) | Event ID | Len (Must be 1) | ‘?’ (0x3f)

– This message shall be responded to with a list of all top-level identifiers that the ICE board is capable of acting usefully upon. That is, if the ICE firmware understands ‘d’ messages but does not have an I2C frontend ‘d’ shall be omitted. Sub-types are not specified by this command. That is, if a version 0.2 ICE includes ‘o’ in its response it is assumed to understand both the ‘oc’ and ‘oo’ messages.
– Both set and query commands should be included in this list. That is, if a GOC frontend is present, both ‘o’ and ‘O’ should be included.
– As example, a version 0.2 ICE with no physical I2C frontend would respond:
ACK (0x00) | Event ID | Len (11) | ‘? IifOoGgPp’ (0x3f5f4969664f6f47675070)

0x3f 0x62 ‘?b’ – Query baudrate

– This message shall mirror the ‘ b’ message and report the currently set baud rate.

0x3f Responses

– NAKs for this message shall be composed of an error code, followed by an optional explanatory string.

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

3.3.2 0x5f ‘ ’ – Configure ICE

Synchronous Request

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

‘ ’ commands are setters for the ’?’ getters if appropriate.

0x5f 0x62 ‘ b’ – Set baudrate

‘ ’ | Event ID | Len (Must be 3) | ‘b’ | Clock Divider

– This message shall set the baud rate for future messages. The new baud rate shall take effect after the ACK for this request.
– This shall be followed by a two byte value N (MSB-first), where N = d

20 MHz
BaudRate e.
– Default: 0x00AE (20 MHz / 0x00AE ≈ 115200 Hz)

– The following message would set the ICE speed to 3 Megabaud:

‘ ’ (0x5f) | Event ID | Length (3) | ‘b’ (0x62) | 0x0007

3.3 Version 0.3 | 3 PROTOCOLS

3.3.3 0x66 ‘f’ – Debug (GOC/EIN) interface message

Synchronous Request

Debug interface messages are formatted the exact same as ‘d’iscrete messages.

3.3.4 0x4f ‘O’ – Query debug (GOC/EIN) Configuration

Synchronous Request

‘O’ (0x4f) | Event ID | Len (Must be 1) | Parameter

These messages complement the set ‘o’ messages.

The ‘Parameter’ field is the parameter specifier to query.

An ACK response should mimic the corresponding set message.

3.3.5 0x6f ‘o’ – Set debug (GOC/EIN) Configuration

Synchronous Request

The first byte of the message shall define which parameter is to be configured.

0x6f 0x63 ‘oc’: Clock Speed (Divider)

‘o’ | Event ID | Len (Must be 5) | ‘c’ | Clock Divider

– Default: 0x0061A800 (4 MHz / 0x0061A800 = .625 Hz)
– This shall be followed by a bour byte value N (MSB-first), where 4 MHz / N yields the desired clock speed.

0x6f 0x70 ‘op’: Debug mode

‘o’ | Event ID | Len (Must be 2) | ‘p’ | GOC / EIN

– Default: 0x0 (EIN)
– Specifies which interface to use when transferring debug data. Possible values: 0 EIN
1 GOC

0x6f 0x6f ‘oo’: GOC light On/Off

‘o’ | Event ID | Len (Must be 2) | ‘o’ | On / Off

– Default: 0x0 (Off)
– This shall be followed by either a 0 or a 1 indicating whether the default state of the light should be on or off. If the default is set to on, the light shall remain illuminated until set to off or a GOC pulse temporarily turns if off.

0x6f Responses

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

3.3 Version 0.3 | 3 PROTOCOLS

3.3.6 0x42 ‘B’ – MBus Snooped Message

Asynchronous Message

‘B’ | Event ID | Len (Min: 5) | MBus Address | MBus Data | MBus Control

This shall be followed by a 32-bit MBus destination address as well as optional data. The current MBus implementation operates on 4-byte words, so the data field length must be a multiple of four. As with discrete (‘d’) messages, the length field limits the maximum message size to 255 bytes. Longer messages should be fragmented.

At the end of the message, snoop messages shall append one additional byte. This additional byte shall indicate the control bits of the snooped message. Control Bit 0 shall be mapped to bit 0 and Control Bit 1 shall be mapped to bit 1. The remaining bits are undefined.

This message is sent only from the ICE board to report messages it has snooped (but not ACK’d).

Messages that match both the ICE address and the snoop address (that is, would generate both ‘b’ and ‘B’ messages) shall not report snoop messages.

The ICE board shall not report snoop messages for message that it is sending.

3.3.7 0x62 ‘b’ – MBus Message

Synchronous Request, Asynchronous Message

MBus messages are formatted the exact same as ‘MBus Snooped’ (‘B’) messages.

This command may be sent to the ICE board to send a message.

This message is sent from the ICE board to report messages sent to ICE. That is messages that matched the address masks assigned to ICE and that ICE has ACK’d on the bus.

3.3.8 0x4d ‘M’ – Query MBus Configuration

Synchronous Request

‘M’ (0x4d) | Event ID | Length | Parameter

These messages complement the set of ‘m’ messages.

The ‘Parameter’ field is the parameter specifier to query.

An ACK response should mimic the corresponding set message.

3.3.9 0x6d ‘m’ – Set MBus Configuration

Synchronous Request

The first byte of the message shall define which parameter is to be configured.

0x6d 0x6c ‘ml’: Set MBus Full Prefix

‘m’ | Event ID | Len (Must be 7) | ‘l’ | Ones Mask | Zeros Mask

– Default: 0xfffff0 0xfffff0 (Disabled)
– NOTE: This command is not supported by the current MBus implementation.
– This shall be followed by 6 bytes. The first three bytes shall be considered the ones mask the second three bytes shall be considered the zeros mask. The masks are 20 bits long, the bottom 4 bits of the transmitted masks shall be ignored.

3.3 Version 0.3 | 3 PROTOCOLS

0x6d 0x73 ‘ms’: Set MBus Short Prefix

‘m’ | Event ID | Len (Must be 3) | ‘s’ | Ones Mask | Zeros Mask

– Default: 0xf0 0xf0 (Disabled)

– NOTE: This command is not supported by the current MBus implementation.
– This shall be followed by 2 bytes. The first byte shall be considered the ones mask the second byte shall be considered the zeros mask. The masks are 4 bits long, the bottom 4 bits of the transmitted masks shall be ignored.
– NOTE: Changing the short prefix after enumeration is a violation of the MBus protocol. The ICE board will permit this, but it may have unexpected consequences.

0x6d 0x4c ‘mL’: Set MBus Snoop Full Prefix

‘m’ | Event ID | Len (Must be 7) | ‘L’ | Ones Mask | Zeros Mask

– Default: 0xfffff0 0xfffff0 (Disabled)

– NOTE: This command is not supported by the current MBus implementation.
– This shall be followed by 6 bytes. The first three bytes shall be considered the ones mask the second three bytes shall be considered the zeros mask. The masks are 20 bits long, the bottom 4 bits of the transmitted masks shall be ignored.
– Messages matching the snoop prefix shall be reported by a ‘B’ message but will not be ACK’d on the physical bus by ICE.
– In the case of a conflict between a snoop and a match, the match takes precedence and ICE will ACK the message.

0x6d 0x53 ‘mS’: Set MBus Snoop Short Prefix

‘m’ | Event ID | Len (Must be 3) | ‘S’ | Ones Mask | Zeros Mask

– Default: 0xf0 0xf0 (Disabled)

– NOTE: This command is not supported by the current MBus implementation.
– This shall be followed by 2 bytes. The first byte shall be considered the ones mask the second byte shall be considered the zeros mask. The masks are 4 bits long, the bottom 4 bits of the transmitted masks shall be ignored.
– Messages matching the snoop prefix shall be reported by a ‘B’ message but will not be ACK’d on the physical bus by ICE.
– In the case of a conflict between a snoop and a match, the match takes precedence and ICE will ACK the message.

0x6d 0x73 ‘mb’: Set MBus Broadcast Mask

‘m’ | Event ID | Len (Must be 1) | ‘b’ | Ones Mask | Zeros Mask

– Default: 0x0f 0x0f (Disabled)

– NOTE: This command is not supported by the current MBus implementation.
– This shall be followed by 2 bytes. The first byte shall be considered the ones mask the second byte shall be considered the zeros mask. The masks are 4 bits long, the top 4 bits of the transmitted masks shall be ignored.
– These masks are the set of broadcast channels that the ICE board should ACK on the physical MBus.

3.3 Version 0.3 | 3 PROTOCOLS

0x6d 0x53 ‘mB’: Set MBus Snoop Broadcast Mask

‘m’ | Event ID | Len (Must be 1) | ‘B’ | Ones Mask | Zeros Mask

– Default: 0x0f 0x0f (Disabled)
– NOTE: This command is not supported by the current MBus implementation.
– This shall be followed by 2 bytes. The first byte shall be considered the ones mask the second byte shall be considered the zeros mask. The masks are 4 bits long, the top 4 bits of the transmitted masks shall be ignored.
– These masks are the set of broadcast channels that the ICE board will not ACK on the physical MBus but will report as a snooped message (a ‘B’ message).
– In the case of a conflict between a snoop and a match, the match takes precedence and ICE will ACK the message.

0x6d 0x6d ‘mm’: Set master mode on/off

‘m’ | Event ID | Len (Must be 2) | ‘m’ | 0x00 or 0x01

– Default: 0x0 (Off)
– Boolean whether ICE should act as the MBus master node (1 - on) or as a MBus member node (0 - off).

0x6d 0x63 ‘mc’: Clock Speed

‘o’ | Event ID | Len (4) | ‘c’ | Clock Divider

– Default: 0x000020 (10 MHz / 0x000020 = 312.5 kHz)
– This shall be followed by a three byte value N (MSB-first), where 10 MHz / N yields the desired clock speed.
– This configuration is meaningful only if ICE is configured as the MBus master node (see ‘mm’).

0x6d 0x69 ‘mi’: Set should interrupt

‘m’ | Event ID | Len (Must be 2) | ‘i’ | SHOULD INT

– Default: 0x0 (Off)
– NOTE: This command is not supported by the current MBus implementation.
– Configures whether ICE should interrupt the bus to transmit its next message. Possible values: 0 Do not interrupt
1 Interrupt (if necessary) for next message only. That is, this value is reset to 0 after the next ‘b’ command sent to ICE is handled.
2 Interrupt for all messages

0x6d 0x70 ‘mp’: Set should use priority arbitration

‘m’ | Event ID | Len (Must be 2) | ‘p’ | SHOULD PRIO

– Default: 0x0 (Off)
– Configures whether ICE should send high priority MBus messages. Possible values: 0 Do not send priority message.
1 Send all messages as high priority.

3.3 Version 0.3 | 3 PROTOCOLS

0x6d Responses

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

3.3.10 0x47 ‘G’ – Query GPIO State / Configuration

Synchronous Request

‘G’ (0x47) | Event ID | Len (Must be 1) | GPIO IDX

These messages complement the set GPIO (‘g’) messages.

An ACK response should mimic the corresponding set message.

3.3.11 0x67 ‘g’ – Set / Configure GPIO

Synchronous Request, Asynchronous Message

The first byte of this message shall be a specificer, indicating what type of GPIO action is requested.

0x67 0x6c ‘gl’ – GPIO Level

‘o’ (0x67) | Event ID | Len (Must be 4) | ‘l’ (0x6c) | GPIO Mask

– Default: 0x000000 (All low)

– This shall be followed by a three byte bitmask indicating the desired output level of all 24 GPIO. This is only reflected in those GPIO which are configured as output. Each bit shall be valued:
- 0: Low (0.0 V)
- 1: High (1.2 V)

0x67 0x64 ‘gd’ – GPIO Direction

‘o’ (0x67) | Event ID | Len (Must be 4)) | ‘d’ (0x64) | GPIO Mask

– Default: 0x000000 (All input)

– This shall be followed by a three byte bitmask indicating the desired direction of all 24 GPIO. The output level of each GPIO which are configured as output are set via the ‘Set GPIO Level’ (‘gl’) command. Each bit shall be valued:

- 0: Input (DEFAULT)
- 1: Output

3.3 Version 0.3 | 3 PROTOCOLS

0x67 0x69 ‘gi’ – GPIO Interrupt Enable

‘o’ (0x67) | Event ID | Len (Must be 4)) | ‘d’ (0x64) | GPIO Mask

– Default: 0x000000 (All interrupts disabled)

– This shall be followed by a three byte bitmask indicating whether a change in each GPIO bit wil generate an GPIO level change message. Only those GPIO which are configured as input will generate interrupts. Each bit shall be valued:
- 0: Interrupt Disabled (DEFAULT)
- 1: Interrupt Enabled

3.3.12 0x50 ‘P’ – Query Power State

Synchronous Request

‘P’ (0x50) | Event ID | Len (Must be 1) | Parameter | PWR IDX

These messages complement the Set Power (‘p’) messages.

The ‘Parameter’ field is the parameter specifier to query.

An ACK response should mimic the corresponding set message.

3.3.13 0x70 ‘p’ – Set Power State

Synchronous Request, Asynchronous Message

Set Power State messages allow direct control of set-point voltage and on/off states for various power domains on the ICE board. The first byte of this message shall be a specificer, indicating which parameter is requested. The second byte of the message shall be the power domain identifier. Currently implemented power domain identifiers are:

– 0: M3 0.6V (0.675V Default)

– 1: M3 1.2V (1.2V Default)

– 2: M3 VBatt (3.8V Default)

– 3: GOC USB Voltage (5.0V Default)

0x70 0x76 ‘pv’ – Voltage State

– The first byte of the message shall be a single byte indicating the power domain identifier to set. The second byte (v set) shall specify the voltage according to the equation:

Vout = (0.537 + 0.0185 ∗ v set) ∗ Vdefault

Valid values for v set range from 0 to 31

‘p’ (0x70) | Event ID | Len (Must be 3) | ‘v’ (0x76) | PWR IDX | v set

0x70 0x6f ‘po’ – On/Off State

– The first byte of the message shall be a single byte indicating the power domain identifier to set. The second byte shall be valued 0 or 1, depending on the desired On/Off state.

‘p’ (0x70) | Event ID | Len (Must be 3) | ‘o’ (0x6f) | PWR IDX | On/Off

4 DOCUMENT REVISION HISTORY

## 4 Document Revision History

Revision 0.2.7 – Oct 29, 2013

Add ‘?c’ message

Add ‘B’, ‘b’, ‘M’, and ‘m’ messages

Add ‘e’ message

Change ‘?c’ to ‘??’

Add ‘ b’ and ‘?b’ messages

Revision 0.2.6 – Oct 17, 2013

Add ‘Oo’ and ‘oo’ messages

Revision 0.2.5 – Jan 14, 2013 Add ‘p’ and ‘P’ messages

Revision 0.2.4 – Dec 20, 2012 Add ‘g’ and ‘G’ messages

Revision 0.2.3 – Dec 18, 2012 Add ‘f’, ‘o’, and ‘O’ messages

Revision 0.2.2 – Dec 15, 2012

‘d’ fragments are 255 bytes long so that a final fragment of maximum length can be distinguished Make explicit that each ‘d’ fragment message is ACK/NAK’d

When a ‘d’ fragment is NAK’d, that ends the transaction

Revision 0.2.1 – Nov 29, 2012
0.1’s ‘d’ → ‘e’

Add fragmented ‘d’ messages

Revision 0.2 – Nov 27, 2012
Largely redefine the protocol (ish)

Revision 0.1.2 – Nov 26, 2012

Restrict Version to ‘V’ only

Restrict eXtension to ‘X’ only

Revision 0.1.1 – Nov 16, 2012 Add visualized packets

Revision 0.1 – Nov 14, 2012

Initial revision

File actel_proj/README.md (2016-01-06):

ICE FPGA HDL
============

This code is synthesized using [Microsemi Libero 11.5.3.10](http://www.microsemi.com/products/fpga-soc/design-resources/design-software/libero-soc) and loaded onto the ICE board's AGLN250V2 FPGA using a [FlashPro4](http://www.microsemi.com/products/fpga-soc/design-resources/programming/flashpro) programmer.  Fully synthesized images can be found in the [fpga_images](fpga_images/) directory.

NOTE: More recent versions of Libero (11.6+) have had issues meeting the size requirements imposed by the IGLOO nano FPGA.

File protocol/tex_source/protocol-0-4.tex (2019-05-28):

\subsection{Version 0.4}
\label{protocol-0-4}

\begin{itemize}

\item Version 0.4 add the following messages:
\begin{itemize}
  \item \texttt{0x65 `e'} -- Exit ICE. Used by software test infrastructure.
  \item \texttt{0x6e `n'} -- Debug (GOC/ICE) interface message with Manchester encoding.
\end{itemize}

\item Version 0.4 modifies the following messages:
\begin{itemize}
  \item Nothing Yet
\end{itemize}

\item Version 0.4 deprecates support for the following messages:
\begin{itemize}
  \item Nothing Yet
\end{itemize}

\end{itemize}

\setcounter{tocdepth}{4}
\etocsettocstyle
    {\subsection*{\contentsname}\hrule\medskip
        \everypar{\rightskip.1\linewidth}}
    {\nobreak\medskip\hrule\bigskip}

\localtableofcontents

\subsubsection{\texttt{0x3f `?'} -- Query ICE}
{\em Synchronous Request}
\begin{itemize}
  \item The first byte of this message shall be a specificer, indicating
    what type of query is requested.
  \paragraph{\texttt{0x3f 0x3f `??'} -- Query capabilities}
    \begin{itemize}
      \item This message shall query the capabilities of this ICE board. Not
        all boards have every hardware frontend. Use this message to query the
        capabilities of a given ICE board.
      \item[]
        \begin{bytefield} \\
          \colorbitbox{lightgreen}{8}{`?' (0x3f)} &
          \colorbitbox{lightred}{8}{Event ID} &
          \colorbitbox{lightcyan}{8}{Len (Must be 1)} &
          \colorbitbox{lightergreen}{8}{`?' (0x3f)}
        \end{bytefield}
      \item This message shall be responded to with a list of all top-level
        identifiers that the ICE board is capable of acting usefully upon.
        That is, if the ICE firmware understands {\tt `d'} messages but does
        not have an I2C frontend {\tt `d'} shall be omitted. Sub-types are not
        specified by this command. That is, if a version 0.2 ICE includes
        {\tt `o'} in its response it is assumed to understand both the
        {\tt `oc'} and {\tt `oo'} messages.
      \item Both set and query commands should be included in this list. That
        is, if a GOC frontend is present, both {\tt `o'} and {\tt `O'}
        should be included.
      \item As example, a version 0.2 ICE with no physical I2C frontend would
        respond:
      \item[]
        \begin{bytefield} \\
          \colorbitbox{lightgreen}{8}{ACK (0x00)} &
          \colorbitbox{lightred}{8}{Event ID} &
          \colorbitbox{lightcyan}{8}{Len (11)} &
          \bitbox{20}{\texttt{`?\_IifOoGgPp' (0x3f5f4969664f6f47675070)}} &
        \end{bytefield}
    \end{itemize}
  \paragraph{\texttt{0x3f 0x62 `?b'} -- Query baudrate}
    \begin{itemize}
      \item This message shall mirror the {\tt `\_b'} message and report the
        currently set baud rate.
    \end{itemize}
  \paragraph{\texttt{0x3f} Responses}
    \begin{itemize}
      \item NAKs for this message shall be composed of an error
        code, followed by an optional explanatory string.
        \begin{itemize}
          \item[]
            \begin{bytefield} \\
              \colorbitbox{lightgreen}{8}{NAK (0x01)} &
              \colorbitbox{lightred}{8}{Event ID} &
              \colorbitbox{lightcyan}{8}{Len (Min: 1)} &
              \colorbitbox{lightblue}{8}{EINVAL (0x16)} &
              \bitbox{8}{[{\tt "Out of Range"}]} &
            \end{bytefield}
          \item {\texttt {\textbf EINVAL (22,0x16):}} Invalid argument.
        \end{itemize}
    \end{itemize}
\end{itemize}

\subsubsection{\texttt{0x5f `\_'} -- Configure ICE}
{\em Synchronous Request}
\begin{itemize}
  \item The first byte of this message shall be a specificer, indicating
    what type of query is requested.
  \item {\tt `\_'} commands are setters for the {\tt '?'} getters if
    appropriate.
  \paragraph{\texttt{0x5f 0x62 `\_b'} -- Set baudrate}
    \begin{itemize}
        \item[]
          \begin{bytefield} \\
            \colorbitbox{lightgreen}{8}{`\_'} &
            \colorbitbox{lightred}{8}{Event ID} &
            \colorbitbox{lightcyan}{8}{Len (Must be 3)} &
            \colorbitbox{lightergreen}{8}{`b'} &
            \bitbox{8}{Clock Divider}
          \end{bytefield}
      \item This message shall set the baud rate for future messages. The new
        baud rate shall take effect after the ACK for this
        request.
      \item This shall be followed by a two byte
        value N (MSB-first), where $N = \lceil\frac{20~MHz}{Baud Rate}\rceil$.
      \item {\bf Default:} {\tt 0x00AE} (20~MHz / 0x00AE $\approx$ 115200~Hz)
      \item The following message would set the ICE speed to 3 Megabaud:
      \item[]
        \begin{bytefield} \\
          \colorbitbox{lightgreen}{8}{`\_' (0x5f)} &
          \colorbitbox{lightred}{8}{Event ID} &
          \colorbitbox{lightcyan}{8}{Length (3)} &
          \colorbitbox{lightergreen}{8}{`b' (0x62)}
          \bitbox{8}{0x0007}
        \end{bytefield}
    \end{itemize}
\end{itemize}

\subsubsection{\texttt{0x66 `f'} -- Debug (GOC/EIN) interface message}
{\em Synchronous Request}
\begin{itemize}
  \item[]
    \begin{bytefield}{40}
      \colorbitbox{lightgreen}{8}{`f'} &
      \colorbitbox{lightred}{8}{Event ID} &
      \colorbitbox{lightcyan}{8}{Length} &
      \bitbox{4}{Data...}
    \end{bytefield}

  \item The bytes in this message compose an GOC/EIN transaction.
  \item The length field of this message necessarily limits the maximum
    message size to 255 bytes (addr + 254 data). Longer messages should
    be fragmented.
  \item The sentinel value {\tt 255} for length indicates a {\em
    fragmented} message.
  \item[]
    \begin{itemize}
      \item A message fragment {\bf MUST} be exactly 255 bytes long.
      \item A fragment message {\bf MUST} be followed by another
        fragment, or terminated by a regular {\bf `f'} message.
        \begin{itemize}
          \item The ICE board is permitted to interleave other,
            non-GOC/EIN related messages (e.g. GPIO events).
        \end{itemize}
      \item A series of message fragments {\bf MUST} always be
        terminated by a `f' message with an explicit length. An `f' transaction of
        length 0 is permitted, e.g.:
        \begin{itemize}
          \item An transaction of length 510 (1 byte addr + 509 bytes
            of data) would be {\bf three} messages. The first of length
            255 (addr + bytes 0-253), the second of length 255 (bytes
            254-508), and the third of length 0 (there is no more
            data, but the fragment series must be terminated).
        \end{itemize}
      \item Fragments are treated as one logical message, but individual bus
        transactions, by an ICE board.  In practice this means:
        \begin{itemize}
          \item Each fragment message must be individually ACK'd by ICE.
            \begin{itemize}
              \item A NAK'd fragment message ends a message.
              \item The NAK offset is relative to the current fragment, not
                the whole transaction.
            \end{itemize}
          \item Only the first fragment includes the GOC address.
        \end{itemize}
    \end{itemize}
  \item ICE will respond with an ACK once every byte from an individual `f'
    message has been transmitted via GOC/EIN.
\end{itemize}

\subsubsection{\texttt{0x6e `n'} -- Debug (GOC/EIN) interface message with Manchester encoding}
{\em Synchronous Request}
\begin{itemize}
  \item[]
    \begin{bytefield}{40}
      \colorbitbox{lightgreen}{8}{`n'} &
      \colorbitbox{lightred}{8}{Event ID} &
      \colorbitbox{lightcyan}{8}{Length} &
      \bitbox{4}{Data...}
    \end{bytefield}

  \item This message is identical to \texttt{`f'} messages.
  \item The ICE board will use the new Manchester modulation scheme instead of
    the old PWM modulation scheme used for \texttt{`f'} messages.
\end{itemize}

\subsubsection{\texttt{0x4f `O'} -- Query debug (GOC/EIN) Configuration}
{\em Synchronous Request}
\begin{itemize}
  \item[]
    \begin{bytefield} \\
      \colorbitbox{lightgreen}{8}{`O' (0x4f)} &
      \colorbitbox{lightred}{8}{Event ID} &
      \colorbitbox{lightcyan}{8}{Len (Must be 1)} &
      \bitbox{8}{Parameter} &
    \end{bytefield}
  \item These messages complement the set {\tt `o'} messages.
  \item The `Parameter' field is the parameter specifier to query.
  \item An ACK response should mimic the corresponding set message.
\end{itemize}

\subsubsection{\texttt{0x6f `o'} -- Set debug (GOC/EIN) Configuration}
{\em Synchronous Request}
\begin{itemize}
  \item The first byte of the message shall define which parameter is to
    be configured.
    \paragraph{\texttt{0x6f 0x63 `oc'}: Clock Speed (Divider)}
      \begin{itemize}
        \item[]
          \begin{bytefield}{2} \\
            \colorbitbox{lightgreen}{8}{`o'} &
            \colorbitbox{lightred}{8}{Event ID} &
            \colorbitbox{lightcyan}{8}{Len (Must be 5)} &
            \colorbitbox{lightergreen}{8}{`c'}  \\
            \bitbox{32}{Clock Divider}
          \end{bytefield}

        \item {\bf Default:} {\tt 0x0061A800} (4~MHz / 0x0061A800 = .625~Hz)
        \item This shall be followed by a bour byte
          value N (MSB-first), where 4~MHz / N yields the desired clock speed.
      \end{itemize}
    \paragraph{\texttt{0x6f 0x70 `op'}: Debug mode}
      \begin{itemize}
        \item[]
          \begin{bytefield} \\
            \colorbitbox{lightgreen}{8}{`o'} &
            \colorbitbox{lightred}{8}{Event ID} &
            \colorbitbox{lightcyan}{8}{Len (Must be 2)} &
            \colorbitbox{lightergreen}{8}{`p'} &
            \bitbox{8}{GOC / EIN}
          \end{bytefield}
        \item {\bf Default:} {\tt 0x0} (EIN)
        \item Specifies which interface to use when transferring debug data.  Possible values:
          \begin{itemize}
            \item[0] EIN
            \item[1] GOC
            \item[3] GOC - Infrared (if not supported falls back to GOC)
          \end{itemize}
      \end{itemize}
    \paragraph{\texttt{0x6f 0x6f `oo'}: GOC light On/Off}
      \begin{itemize}
        \item[]
          \begin{bytefield} \\
            \colorbitbox{lightgreen}{8}{`o'} &
            \colorbitbox{lightred}{8}{Event ID} &
            \colorbitbox{lightcyan}{8}{Len (Must be 2)} &
            \colorbitbox{lightergreen}{8}{`o'} &
            \bitbox{8}{On / Off}
          \end{bytefield}
        \item {\bf Default:} {\tt 0x0} (Off)
        \item This shall be followed by either a {\tt 0} or a {\tt 1}
          indicating whether the default state of the light should be on or
          off. If the default is set to on, the light shall remain illuminated
          until set to off or a GOC pulse temporarily turns if off.
      \end{itemize}
  \paragraph{\texttt{0x6f} Responses}
    \begin{itemize}
      \item NAKs for this message shall be composed of an error
        code, followed by an optional explanatory string.
        \begin{itemize}
          \item[]
            \begin{bytefield} \\
              \colorbitbox{lightgreen}{8}{NAK (0x01)} &
              \colorbitbox{lightred}{8}{Event ID} &
              \colorbitbox{lightcyan}{8}{Len (Min: 1)} &
              \colorbitbox{lightblue}{8}{EINVAL (0x16)} &
              \bitbox{8}{[{\tt "Out of Range"}]} &
            \end{bytefield}
          \item {\texttt {\textbf EINVAL (22,0x16):}} Invalid argument.
        \end{itemize}
    \end{itemize}
\end{itemize}

\subsubsection{\texttt{0x42 `B'} -- MBus Snooped Message}
{\em Asynchronous Message}
\begin{itemize}
  \item[]
    \begin{bytefield} \\
      \colorbitbox{lightgreen}{8}{`B'} &
      \colorbitbox{lightred}{8}{Event ID} &
      \colorbitbox{lightcyan}{8}{Len (Min: 5)} &
      \colorbitbox{lightergreen}{8}{MBus Address} &
      \bitbox{8}{MBus Data} &
      \bitbox{8}{MBus Control}
    \end{bytefield}
  \item This shall be followed by a 32-bit MBus destination address as well as optional data.
    The current MBus implementation operates on 4-byte words, so the data field length must be a multiple of four.
    As with discrete ({\tt `d'}) messages, the length field limits the maximum message size to 255 bytes.  Longer messages should be fragmented.
  \item At the end of the message, snoop messages shall append one additional
    control byte:
    \subitem Bit~0: Control Bit 0
    \subitem Bit~1: Control Bit 1
    \subitem Bit~2: RX was broadcast
    \subitem Bit~3: RX had an error
  \item This message is sent only from the ICE board to report messages it has
    snooped (but not ACK'd).
  \item Messages that match both the ICE address and the snoop address (that
    is, would generate both {\tt `b'} and {\tt `B'} messages) shall not report
    snoop messages.
  \item The ICE board shall not report snoop messages for message that it is sending.
\end{itemize}

\subsubsection{\texttt{0x62 `b'} -- MBus Message}
{\em Synchronous Request, Asynchronous Message}
\begin{itemize}
  \item[]
    \begin{bytefield}{2} \\
      \colorbitbox{lightgreen}{8}{`b' (0x62)} &
      \colorbitbox{lightred}{8}{Event ID} &
      \colorbitbox{lightcyan}{8}{Len (Min: 5)}  &
      \colorbitbox{lightergreen}{32}{MBus Address} \\
      \bitbox{32}{MBus Data} 
    \end{bytefield}

  \item MBus messages are formatted the exact same as `MBus Snooped' ({\tt `B'}) messages.
  \item This command may be sent to the ICE board to send a message.
  \item This message is sent from the ICE board to report messages sent to
    ICE. That is messages that matched the address masks assigned to ICE and
    that ICE has ACK'd on the bus.
\end{itemize}

\subsubsection{\texttt{0x65 `e'} -- Exit ICE}
{\em Asynchronous Message}
\begin{itemize}
  \item[]
    \begin{bytefield} \\
      \colorbitbox{lightgreen}{8}{`e'} &
      \colorbitbox{lightred}{8}{Event ID} &
      \colorbitbox{lightcyan}{8}{Len (must be 4)} &
      \colorbitbox{lightergreen}{32}{Exit\_Code} 
    \end{bytefield}
  \item This command shall terminate the m3\_ice program with exit code
  \textit{Exit\_Code}.  This is used for testing of the ICE system.  
  \item \textit{Len} must be 0x04
  \item \textit{Exit\_Code} must be 4 bytes 
\end{itemize}

\subsubsection{\texttt{0x4d `M'} -- Query MBus Configuration}
{\em Synchronous Request}
\begin{itemize}
  \item[]
    \begin{bytefield} \\
      \colorbitbox{lightgreen}{8}{`M' (0x4d)} &
      \colorbitbox{lightred}{8}{Event ID} &
      \colorbitbox{lightcyan}{8}{Length} &
      \bitbox{8}{Parameter} &
    \end{bytefield}
  \item These messages complement the set of {\tt `m'} messages.
  \item The `Parameter' field is the parameter specifier to query.
  \item An ACK response should mimic the corresponding set message.
\end{itemize}

\subsubsection{\texttt{0x6d `m'} -- Set MBus Configuration}
{\em Synchronous Request}
\begin{itemize}
  \item The first byte of the message shall define which parameter is to
    be configured.
    \paragraph{\texttt{0x6d 0x72 `mr'}: Assert Internal MBus Reset}
      \begin{itemize}
        \item[]
          \begin{bytefield} \\
            \colorbitbox{lightgreen}{8}{`m'} &
            \colorbitbox{lightred}{8}{Event ID} &
            \colorbitbox{lightcyan}{8}{Len (Must be 2)} &
            \colorbitbox{lightergreen}{8}{`r'} &
            \bitbox{8}{MBus Reset}
          \end{bytefield}
        \item {\bf Default:} {\tt 0x0} (Disabled)
        \item This command controls a signal that will hold the internal MBus
          module in reset. While in reset, COUT and DOUT are held high. This
          is useful for bootstrapping when tying multiple ice boards together
          in a loop.
      \end{itemize}
    \paragraph{\texttt{0x6d 0x6c `ml'}: Set MBus Full Prefix}
      \begin{itemize}
        \item[]
          \begin{bytefield} \\
            \colorbitbox{lightgreen}{8}{`m'} &
            \colorbitbox{lightred}{8}{Event ID} &
            \colorbitbox{lightcyan}{8}{Len (Must be 4)} &
            \colorbitbox{lightergreen}{8}{`l'} &
            \bitbox{8}{Full Prefix}
          \end{bytefield}
        \item {\bf Default:} {\tt 0xXfffff} (Disabled)
        \item This shall be followed by 3 bytes. An MBus full prefix is
          20~bits long, the top 4~bits shall be ignored.
      \end{itemize}
    \paragraph{\texttt{0x6d 0x73 `ms'}: Set MBus Short Prefix Override}
      \begin{itemize}
        \item[]
          \begin{bytefield} \\
            \colorbitbox{lightgreen}{8}{`m'} &
            \colorbitbox{lightred}{8}{Event ID} &
            \colorbitbox{lightcyan}{8}{Len (Must be 2)} &
            \colorbitbox{lightergreen}{8}{`s'} &
            \bitbox{8}{Short Prefix}
          \end{bytefield}
        \item {\bf Default:} {\tt 0xXf} (Disabled)
        \item This shall be followed by 1 byte. An MBus short prefix is 4~bits
          long, the top 4~bits shall be ignored.
        \item If this value is not set, the ICE board will participate in
          enumeration. If this value is set after enumeration, it will
          override the selected address.
        \item The current ICE protocol does not have a command for reading out
          the state of internal enumeration (whether ICE has been enumerated
          and what address it was assigned).
        \item {\bf NOTE:} Changing the short prefix after enumeration is a
          violation of the MBus protocol. The ICE board will permit this, but
          it may have unexpected consequences.
      \end{itemize}
    \paragraph{\texttt{0x6d 0x53 `mS'}: Enable MBus Snooping}
      \begin{itemize}
        \item[]
          \begin{bytefield} \\
            \colorbitbox{lightgreen}{8}{`m'} &
            \colorbitbox{lightred}{8}{Event ID} &
            \colorbitbox{lightcyan}{8}{Len (Must be 2)} &
            \colorbitbox{lightergreen}{8}{`S'} &
            \bitbox{8}{Snoop Enabled}
          \end{bytefield}
        \item {\bf Default:} {\tt 0x00} (Disabled)
        \item If snooping is enabled, the ICE board shall report every MBus
          message that it sees.
        \item Snooped messages shall be reported by a {\tt `B'} message but
          will not be ACK'd on the physical bus by ICE.
        \item In the case of a conflict between a snoop and a match, the match
          takes precedence and ICE will ACK the message.
      \end{itemize}
    \paragraph{\texttt{0x6d 0x73 `mb'}: Set MBus Broadcast Mask}
      \begin{itemize}
        \item[]
          \begin{bytefield} \\
            \colorbitbox{lightgreen}{8}{`m'} &
            \colorbitbox{lightred}{8}{Event ID} &
            \colorbitbox{lightcyan}{8}{Len (Must be 1)} &
            \colorbitbox{lightergreen}{8}{`b'} &
            \bitbox{8}{Ones Mask} &
            \bitbox{8}{Zeros Mask}
          \end{bytefield}
        \item {\bf Default:} {\tt 0x0f 0x0f} (Disabled)
        \item \hl{NOTE: This command is not supported by the current MBus implementation.}
        \item This shall be followed by 2 bytes. The first byte shall
          be considered the ones mask the second byte shall be
          considered the zeros mask. The masks are 4~bits long, the top
          4~bits of the transmitted masks shall be ignored.
        \item These masks are the set of broadcast channels that the ICE board
          should ACK on the physical MBus.
      \end{itemize}
    \paragraph{\texttt{0x6d 0x53 `mB'}: Set MBus Snoop Broadcast Mask}
      \begin{itemize}
        \item[]
          \begin{bytefield} \\
            \colorbitbox{lightgreen}{8}{`m'} &
            \colorbitbox{lightred}{8}{Event ID} &
            \colorbitbox{lightcyan}{8}{Len (Must be 1)} &
            \colorbitbox{lightergreen}{8}{`B'} &
            \bitbox{8}{Ones Mask} &
            \bitbox{8}{Zeros Mask}
          \end{bytefield}
        \item {\bf Default:} {\tt 0x0f 0x0f} (Disabled)
        \item \hl{NOTE: This command is not supported by the current MBus implementation.}
        \item This shall be followed by 2 bytes. The first byte shall
          be considered the ones mask the second byte shall be
          considered the zeros mask. The masks are 4~bits long, the top
          4~bits of the transmitted masks shall be ignored.
        \item These masks are the set of broadcast channels that the ICE board
          will not ACK on the physical MBus but will report as a snooped
          message (a {\tt `B'} message).
        \item In the case of a conflict between a snoop and a match, the match
          takes precedence and ICE will ACK the message.
      \end{itemize}
    \paragraph{\texttt{0x6d 0x6d `mm'}: Set master mode on/off}
      \begin{itemize}
        \item[]
          \begin{bytefield} \\
            \colorbitbox{lightgreen}{8}{`m'} &
            \colorbitbox{lightred}{8}{Event ID} &
            \colorbitbox{lightcyan}{8}{Len (Must be 2)} &
            \colorbitbox{lightergreen}{8}{`m'} &
            \bitbox{8}{\texttt{0x00} or \texttt{0x01}}
          \end{bytefield}
        \item {\bf Default:} {\tt 0x0} (Off)
        \item Boolean whether ICE should act as the MBus master node (1 - on)
          or as a MBus member node (0 - off).
      \end{itemize}
    \paragraph{\texttt{0x6d 0x63 `mc'}: Clock Speed}
      \begin{itemize}
        \item[]
          \begin{bytefield} \\
            \colorbitbox{lightgreen}{8}{`o'} &
            \colorbitbox{lightred}{8}{Event ID} &
            \colorbitbox{lightcyan}{8}{Len (4)} &
            \colorbitbox{lightergreen}{8}{`c'} &
            \bitbox{8}{Clock Divider}
          \end{bytefield}
        \item {\bf Default:} {\tt 0x000020} (10~MHz / 0x000020 = 312.5~kHz)
        \item This shall be followed by a three byte value N (MSB-first), where 10~MHz / N yields the desired clock speed.
        \item This configuration is meaningful only if ICE is configured as
          the MBus master node (see {\tt `mm'}).
      \end{itemize}
    \paragraph{\texttt{0x6d 0x69 `mi'}: Set should interrupt}
      \begin{itemize}
        \item[]
          \begin{bytefield} \\
            \colorbitbox{lightgreen}{8}{`m'} &
            \colorbitbox{lightred}{8}{Event ID} &
            \colorbitbox{lightcyan}{8}{Len (Must be 2)} &
            \colorbitbox{lightergreen}{8}{`i'} &
            \bitbox{8}{{\tt SHOULD\_INT}}
          \end{bytefield}
        \item {\bf Default:} {\tt 0x0} (Off)
        \item \hl{NOTE: This command is not supported by the current MBus implementation.}
        \item Configures whether ICE should interrupt the bus to transmit its
          next message. Possible values:
          \begin{itemize}
            \item[0] Do not interrupt
            \item[1] Interrupt (if necessary) for next message only. That is,
              this value is reset to 0 after the next {\tt `b'} command sent
              to ICE is handled.
            \item[2] Interrupt for all messages
          \end{itemize}
      \end{itemize}
    \paragraph{\texttt{0x6d 0x70 `mp'}: Set should use priority arbitration}
      \begin{itemize}
        \item[]
          \begin{bytefield} \\
            \colorbitbox{lightgreen}{8}{`m'} &
            \colorbitbox{lightred}{8}{Event ID} &
            \colorbitbox{lightcyan}{8}{Len (Must be 2)} &
            \colorbitbox{lightergreen}{8}{`p'} &
            \bitbox{8}{{\tt SHOULD\_PRIO}}
          \end{bytefield}
        \item {\bf Default:} {\tt 0x0} (Off)
        \item Configures whether ICE should send high priority MBus messages. Possible values:
          \begin{itemize}
            \item[0] Do not send priority message.
            \item[1] Send all messages as high priority.
          \end{itemize}
      \end{itemize}
  \paragraph{\texttt{0x6d} Responses}
    \begin{itemize}
      \item NAKs for this message shall be composed of an error
        code, followed by an optional explanitory string.
        \begin{itemize}
          \item[]
            \begin{bytefield} \\
              \colorbitbox{lightgreen}{8}{NAK (0x01)} &
              \colorbitbox{lightred}{8}{Event ID} &
              \colorbitbox{lightcyan}{8}{Len (Min: 1)} &
              \colorbitbox{lightblue}{8}{EINVAL (0x16)} &
              \bitbox{8}{[{\tt "Out of Range"}]} &
            \end{bytefield}
          \item {\texttt {\textbf EINVAL (22,0x16):}} Invalid argument.
          \item[]
            \begin{bytefield} \\
              \colorbitbox{lightgreen}{8}{NAK (0x01)} &
              \colorbitbox{lightred}{8}{Event ID} &
              \colorbitbox{lightcyan}{8}{Len (Min: 1)} &
              \colorbitbox{lightblue}{8}{ENODEV (0x13)} &
            \end{bytefield}
          \item {\texttt {\textbf ENODEV (19,0x13):}} The
            implementation does not support changing or querying this parameter. Unless
            otherwise specified, it {\bf MUST} be hardcoded to the default.
        \end{itemize}
    \end{itemize}
\end{itemize}

\subsubsection{\texttt{0x47 `G'} -- Query GPIO State / Configuration}
{\em Synchronous Request}
\begin{itemize}
  \item[]
    \begin{bytefield} \\
      \colorbitbox{lightgreen}{8}{`G' (0x47)} &
      \colorbitbox{lightred}{8}{Event ID} &
      \colorbitbox{lightcyan}{8}{Len (Must be 1)} &
      \bitbox{8}{GPIO IDX}
    \end{bytefield}
  \item These messages complement the set GPIO (`g') messages.
  \item An ACK response should mimic the corresponding set message.
\end{itemize}

\subsubsection{\texttt{0x67 `g'} -- Set / Configure GPIO}
{\em Synchronous Request, Asynchronous Message}
\begin{itemize}
  \item The first byte of this message shall be a specificer, indicating
    what type of GPIO action is requested.
  \paragraph{\texttt{0x67 0x6c `gl'} -- GPIO Level}
    \begin{itemize}
      \item[]
        \begin{bytefield} \\
          \colorbitbox{lightgreen}{8}{`o' (0x67)} &
          \colorbitbox{lightred}{8}{Event ID} &
          \colorbitbox{lightcyan}{8}{Len (Must be 4)} &
          \colorbitbox{lightergreen}{8}{`l' (0x6c)} &
          \bitbox{8}{GPIO Mask}
        \end{bytefield}
      \item {\bf Default:} {\tt 0x000000} (All low)
      \item This shall be followed by a three byte bitmask indicating the desired output level of all 24 GPIO.  This is only reflected in those GPIO which are configured as output. Each bit shall be valued:
      \begin{itemize}
        \item 0: Low (0.0 V)
        \item 1: High (1.2 V)
      \end{itemize}
    \end{itemize}
  \paragraph{\texttt{0x67 0x64 `gd'} -- GPIO Direction}
    \begin{itemize}
      \item[]
        \begin{bytefield} \\
          \colorbitbox{lightgreen}{8}{`o' (0x67)} &
          \colorbitbox{lightred}{8}{Event ID} &
          \colorbitbox{lightcyan}{8}{Len (Must be 4))} &
          \colorbitbox{lightergreen}{8}{`d' (0x64)} &
          \bitbox{8}{GPIO Mask}
        \end{bytefield}
      \item {\bf Default:} {\tt 0x000000} (All input)
      \item This shall be followed by a three byte bitmask indicating the desired direction of all 24 GPIO.  The output level of each GPIO which are configured as output are set via the `Set GPIO Level' ({\tt `gl'}) command.  Each bit shall be valued:
        \begin{itemize}
          \item 0: Input (DEFAULT)
          \item 1: Output
        \end{itemize}
    \end{itemize}
  \paragraph{\texttt{0x67 0x69 `gi'} -- GPIO Interrupt Enable}
    \begin{itemize}
      \item[]
        \begin{bytefield} \\
          \colorbitbox{lightgreen}{8}{`o' (0x67)} &
          \colorbitbox{lightred}{8}{Event ID} &
          \colorbitbox{lightcyan}{8}{Len (Must be 4))} &
          \colorbitbox{lightergreen}{8}{`d' (0x64)} &
          \bitbox{8}{GPIO Mask}
        \end{bytefield}
      \item {\bf Default:} {\tt 0x000000} (All interrupts disabled)
      \item This shall be followed by a three byte bitmask indicating whether a change in each GPIO bit wil generate an GPIO level change message.  Only those GPIO which are configured as input will generate interrupts.  Each bit shall be valued:
        \begin{itemize}
          \item 0: Interrupt Disabled (DEFAULT)
          \item 1: Interrupt Enabled
        \end{itemize}
    \end{itemize}
%  \paragraph{\texttt{0x67} Responses}
%    \begin{itemize}
%      \item {\texttt {\textbf ENODEV (19,0x13):}} The requested
%        GPIO does not exist.
%      \item[]
%        \begin{bytefield} \\
%          \colorbitbox{lightgreen}{8}{NAK (0x01)} &
%          \colorbitbox{lightred}{8}{Event ID} &
%          \colorbitbox{lightcyan}{8}{Len (Min: 1)} &
%          \colorbitbox{lightblue}{8}{ENODEV (0x13)} &
%          \bitbox{8}{[{\tt "No such GPIO"}]} &
%        \end{bytefield}
%      \item {\texttt {\textbf EINVAL (22,0x16):}} The requested GPIO
%        exists, but cannot be configured this way at this time.
%      \item[]
%        \begin{bytefield} \\
%          \colorbitbox{lightgreen}{8}{NAK (0x01)} &
%          \colorbitbox{lightred}{8}{Event ID} &
%          \colorbitbox{lightcyan}{8}{Len (Min: 1)} &
%          \colorbitbox{lightblue}{8}{EINVAL (0x16)} &
%          \bitbox{8}{[{\tt "GPIO is input"}]} &
%        \end{bytefield}
%    \end{itemize}
\end{itemize}

\subsubsection{\texttt{0x50 `P'} -- Query Power State}
{\em Synchronous Request}
\begin{itemize}
  \item[]
    \begin{bytefield} \\
      \colorbitbox{lightgreen}{8}{`P' (0x50)} &
      \colorbitbox{lightred}{8}{Event ID} &
      \colorbitbox{lightcyan}{8}{Len (Must be 1)} &
      \colorbitbox{lightergreen}{8}{Parameter} &
      \bitbox{8}{PWR IDX}
    \end{bytefield}
  \item These messages complement the Set Power (`p') messages.
  \item The `Parameter' field is the parameter specifier to query.
  \item An ACK response should mimic the corresponding set message.
\end{itemize}

\subsubsection{\texttt{0x70 `p'} -- Set Power State}
{\em Synchronous Request, Asynchronous Message}
\begin{itemize}
  \item Set Power State messages allow direct control of set-point voltage and on/off states for various power domains on the ICE board.  The first byte of this message shall be a specificer, indicating which parameter is requested.  The second byte of the message shall be the power domain identifier.  Currently implemented power domain identifiers are:
   \begin{itemize}
     \item 0: M3 0.6V (0.675V Default)
     \item 1: M3 1.2V (1.2V Default)
     \item 2: M3 VBatt (3.8V Default)
     \item 3: GOC USB Voltage (5.0V Default)
   \end{itemize}
  \paragraph{\texttt{0x70 0x76 `pv'} -- Voltage State}
    \begin{itemize}
      \item The first byte of the message shall be a single byte indicating the power domain identifier to set.  The second byte ($v\_set$) shall specify the voltage according to the equation:
$$V_{out} = (0.537 + 0.0185*v\_set)*V_{default}$$
      Valid values for $v\_set$ range from {\tt 0} to {\tt 31}
      \item[]
        \begin{bytefield} \\
          \colorbitbox{lightgreen}{8}{`p' (0x70)} &
          \colorbitbox{lightred}{8}{Event ID} &
          \colorbitbox{lightcyan}{8}{Len (Must be 3)} &
          \colorbitbox{lightergreen}{8}{`v' (0x76)} &
          \bitbox{8}{PWR IDX} &
          \bitbox{8}{$v\_set$}
        \end{bytefield}
    \end{itemize}
  \paragraph{\texttt{0x70 0x6f `po'} -- On/Off State}
    \begin{itemize}
      \item The first byte of the message shall be a single byte indicating the power domain identifier to set.  The second byte shall be
        valued {\tt 0} or {\tt 1}, depending on the desired On/Off
        state.
      \item[]
        \begin{bytefield} \\
          \colorbitbox{lightgreen}{8}{`p' (0x70)} &
          \colorbitbox{lightred}{8}{Event ID} &
          \colorbitbox{lightcyan}{8}{Len (Must be 3)} &
          \colorbitbox{lightergreen}{8}{`o' (0x6f)} &
          \bitbox{8}{PWR IDX} &
          \bitbox{8}{On/Off}
        \end{bytefield}
    \end{itemize}
\end{itemize}

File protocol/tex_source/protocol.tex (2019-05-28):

\documentclass{article}
\usepackage[layout=letterpaper,margin=1in]{geometry}

\usepackage{fancyhdr}
\usepackage{xspace}
\usepackage{color}
\usepackage{comment}
\usepackage{soul} % provides \hl{}
\newcommand{\hlc}[2][yellow]{{\sethlcolor{#1}\hl{#2}}}

\usepackage[colorlinks=true]{hyperref}

\usepackage[all=normal,lists]{savetrees}

\usepackage[endianness=big]{bytefield}
\bytefieldsetup{boxformatting={\centering\footnotesize}}

\usepackage{etoc}
\setcounter{tocdepth}{4}

\newcommand{\colorbitbox}[3]{%
\rlap{\bitbox{#2}{\color{#1}\rule{\width}{\height}}}%
\bitbox{#2}{#3}}
\definecolor{lightblue}{RGB}{0,204,255}
\definecolor{lightcyan}{rgb}{0.84,1,1}
\definecolor{lightgreen}{rgb}{0.64,1,0.71}
\definecolor{lightergreen}{rgb}{0.84,1,0.87}
\definecolor{lightred}{rgb}{1,0.7,0.71}

\usepackage{enumitem}
\setlistdepth{8}
%\setlist[itemize,1]{label=$\bullet$}
\setlist[itemize,1]{label=}
\setlist[itemize,2]{label=--}
\setlist[itemize,3]{label=$\circ$}
\setlist[itemize,4]{label=$\rightarrow$}
\setlist[itemize,5]{label=$\diamondsuit$}
\setlist[itemize,6]{label=$\cdot$}
\setlist[itemize,7]{label=$\star$}
\setlist[itemize,8]{label=$\ast$}
\renewlist{itemize}{itemize}{8}

\begin{document}

\fancyfoot[L]{Revision 0.3 -- May 28, 2019}
\pagestyle{fancyplain}

\title{ICE Debug Board FPGA Interface protocol}
\author{Ben Kempke, Pat Pannuto \{bpkempke,ppannuto\}@umich.edu}
\date{Revision 0.3 --- May 28, 2019}
\maketitle

\section*{Introduction}
The ICE board is a dual-purpose development board, enabling both high-speed
programming (via DMA) of M3 chips and interfacing with live M3 sessions and
external peripherals.

This means that libraries must be able to gracefully handle asychronous,
unexpected events. In particular, some semantics resemebling transactions
would be desirable, as well as an effort to maintain event ordering over the
serial communications link. The consequence is that this document should be
viewed less as a protocol specification and more of a living document as we
explore the best semantics for this domain.

At a high-level, every message is a composition of an {\em event id}, a
{\em message type} and an optional {\em message}. Every message sent {\em to}
the ICE board {\bf MUST} be replied to by either an ACK or NAK response.
Every message sent {\em from} the ICE board {\bf MUST
NOT} be acknowledged. The rationale for this asymmetry is to simplify the ICE
hardware design. With this mechanism, the hardware is not obligated to
preserve any communication state beyond the immediate running context. The
event ids provide a total ordering of the event history, insofar as is
possible.

\setcounter{tocdepth}{2}
%http://tex.stackexchange.com/questions/87709/minitoc-of-a-subsection/87716
%\etocsettocstyle{\subsection*{\contentsname}\hrule\medskip
%\begin{minipage}{.95\linewidth}}
%{\end{minipage}\medskip\hrule}
%\etocsettocstyle
%    {\subsection*{\contentsname}\hrule\medskip
%        \everypar{\rightskip.1\linewidth}}
%    {\nobreak\medskip\hrule\bigskip}
\tableofcontents

\clearpage
\section{Event Ids}
\label{sec:ids}

\subsection{Motivation}
Some decisions in microcontrollers necessarily race. As contrived example, if
two GPIO pins are defined as interrupts but are electrically connected in the
external circuit, and then line is pulled high, which interrupt fires first?
While the decision is arbitrary, there is motivation to define an ordering of
events in the system. The events observed by ICE can be replayed in the
M-ultaor for debugging, but the is only possible if they can be accurately
re-created.

In practice, this diverges to two ideas:

\subsubsection{Concurrent Events}
Two events could be labeled with the same event id, indicating that they
occurred too close together in time for the ICE to distinguish them. This
would require divergence in the simulator for debugging runs; do-able, but not
trivial.
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

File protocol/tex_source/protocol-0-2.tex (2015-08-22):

\subsection{Version 0.2}
\label{protocol-0-2}

Version 0.2 adds the following new messages:
\begin{itemize}
  \item {\tt `Oo'} and {\tt `oo'}. These messages allow the default on/off state of
the GOC light to be set.
  \item {\tt `??'}. This message queries the capabilities of the ICE board.
  \item {\tt `?B'}, {\tt `?b'}. These messages get and set the ICE baud rate.
  \item {\tt `B'}, {\tt `b'}, {\tt `M'}, and {\tt `m'}. These messages control
    the MBus interface.
  \item {\tt `e'}. This command injects messages on the {\tt EIN} debug port.
\end{itemize}
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

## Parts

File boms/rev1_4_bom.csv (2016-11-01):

Designator | DistPartNo | Footprint | ManPartNo | Quantity
C1, C4, C6, C8, C10, C12, C14, C16, C18, C20 | 445-1311-1-ND | 1608[0603] | C1608X7R1H103K | 10
C2, C27, C29, C30, C32, C33, C35, C37, C38, C39, C40, C42, C43, C61, C65 | 445-6857-1-ND | 0805 | C2012X7R1A106K | 15
C3, C5, C7, C9, C11, C13, C15, C17, C19, C24, C26, C31, C34, C46, C48, C50, C51, C52, C53, C54, C55 | 1276-1005-1-ND | 1608[0603] | CL10B104KO8NNNC | 21
C21, C22, C23 | 399-7893-1-ND | 1608[0603] | C0603C302K5GACTU | 3
C25, C36, C41, C44, C45 | 445-1235-1-ND | 0402 | C1005C0G1H100D | 5
C28, FD1, FD2, FD3, R1, R2, R3, R53, TP1, TP14, TP16, TP17, TP18, TP19, TP20, TP21, TP22, TP23, TP24, TP26, TP27, TP28 |  | 0402, FIDUCIAL, FIDUCIAL, FIDUCIAL, 0603, 0603, 0603, 0402, TP, TP, TP, TP, TP, TP, TP, TP, TP, TP, TP, TP, TP, TP |  | 22
C47, C56 | 1276-1019-1-ND | 1608[0603] | CL10B105KO8NNNC | 2
C49 | 478-1232-1-ND | 1608[0603] | 06035C273KAT2A | 1
C62, C63 | 445-4991-1-ND | 0402 | C1005X5R1A105M | 2
D2 | BAT54-FDICT-ND | SOT-23_N | BAT54-7-F | 1
DIP1 | 450-1364-ND | DIP-8 | ADE0404 | 1
F1 | 1100-1134-ND | VQ100_N | AGLN250V2-VQG100 | 1
F2 | MICROSMD050FCT-ND | 1210 | MICROSMD050F-2 | 1
FB1 | 445-6165-1-ND | Ferrite_Bead_3.2mm_1.6mm | HF30ACC321611-T | 1
H2 | H2961CT-ND | USB Mini-B | UX60A-MB-5ST | 1
I1, I2, I3, I4 | 541-1327-1-ND | INDUCTOR_.118x.142mm | IHLP1212AEER1R0M11 | 4
LED1, LED2, LED3, LED4, LED9 | 160-1169-1-ND | 1206_LED | LTST-C150GKT | 5
P1 | A26530-05-ND | HDR2X5 | 4-103328-0-05 | 1
P2, P5, P10, P15 | A26530-04-ND | HDR2X4 | 4-103328-0-04 | 4
P3 | A31726-ND | USB_HORIZONTAL | 292303-1 | 1
P4 | A26514-12-ND | HDR1X12 | 4-103327-0-12 | 1
P6 | A26530-24-ND | HDR2X24 | 4-103328-0-24 | 1
P7 | A26525-03-ND | HDR2X3 | 4-103777-0-03 | 1
P8, P11, P16 | A26514-02-ND | HDR1X2 | 4-103327-0-02 | 3
P9 | A26530-08-ND | HDR2X8 | 4-103328-0-08 | 1
P12 | A26530-06-ND | HDR2X6 | 4-103328-0-06 | 1
Q2 | SI3477DV-T1-GE3CT-ND | TSOP-6 | SI3477DV-T1-GE3 | 1
R4, R13, R14, R16, R45, R52 | P4.7KGCT-ND | 0603 | ERJ-3GEYJ472V | 6
R5, R6, R7, R8, R98 | P470GCT-ND | 0603 | ERJ-3GEYJ471V | 5
R9, R63, R65, R66, R67, R68, R69, R70, R71, R72 | P47KGCT-ND, P10KGCT-ND, P10KGCT-ND, P10KGCT-ND, P10KGCT-ND, P10KGCT-ND, P10KGCT-ND, P10KGCT-ND, P10KGCT-ND, P10KGCT-ND | 0603 | ERJ-3GEYJ103V | 10
R10, R11 | P1.0KGCT-ND | 0603 | ERJ-3GEYJ102V | 2
R12, R44, R55, R58, R86 | P10.0KLCT-ND | 0402 | ERJ-2RKF1002X | 5
R15, R87, R88, R89, R90, R91 | P68.0KLCT-ND | 0402 | ERJ-2RKF6802X | 6
R17, R18, R19, R20, R21, R22, R23, R24, R25, R26, R27, R28, R29, R30, R31, R32, R33, R34, R35, R36, R37, R38, R39, R40, R73, R74, R75, R76 | P47GCT-ND | 0603 | ERJ-3GEYJ470V | 28
R41, R42, R77, R78, R79, R80, R81, R82, R83, R84, R85, R92, R95, R96, R97, R99, R100, R101, R102 | P0.0GCT-ND | 0603 | ERJ-3GEY0R00V | 19
R43 | P12.0KLCT-ND | 0402 | ERJ-2RKF1202X | 1
R46 | 311-13.0KLRCT-ND | 0402 | RC0402FR-0713KL | 1
R47 | P51.0KLCT-ND | 0402 | ERJ-2RKF5102X | 1
R48 | P11.0KLCT-ND | 0402 | ERJ-2RKF1102X | 1
R49 | P75.0KLCT-ND | 0402 | ERJ-2RKF7502X | 1
R50 | RMCF0402FT24K0CT-ND | 0402 | RMCF0402FT24K0 | 1
R51, R93 | P0.0JCT-ND | 0402 | ERJ-2GE0R00X | 2
R54 | P20.0KLCT-ND | 0402 | ERJ-2RKF2002X | 1
R56, R57 | P4.70KLCT-ND | 0402 | ERJ-2RKF4701X | 2
R59, R61 | P22GCT-ND | 0603 | ERJ-3GEYJ220V | 2
R60 | P2.7KGCT-ND | 0603 | ERJ-3GEYJ272V | 1
R64 | P220KGCT-ND | 0603 | ERJ-3GEYJ224V | 1
R94 | P1.00KLCT-ND | 0402 | ERJ-2RKF1001X | 1
S1, S2, S3, S4 | P8008S-ND | EVQPA | EVQ-PAE04M | 4
S5, S6, S7 | CKN9565-ND | SPDT_SW2 | OS102011MS2QN1 | 3
U1 | 3M5066-ND | CPGA-65 | 200-6310-9UN-1900 | 1
U2, U5, U6 | 296-25596-1-ND | VFSOP-8 | SN74AUP3G17DCUR | 3
U3 | FDC6330LCT-ND | SUPERSOT-6 | FDC6330L | 1
U4 | LTC3589EUJ-2#PBF-ND | QFN-40 | LTC3589EUJ-2#PBF | 1
U7 | 768-1007-1-ND | SSOP20 | FT232RL-REEL | 1
U8, U17, U18 | 296-17705-1-ND | SOT25 | TS5A4594DBVR | 3
U10 | 497-11882-1-ND | SOT23-6_L | USBLC6-2SC6Y | 1
X1 | 535-9565-1-ND | CRYSTAL_3.2mm_2.5mm | ASE-20.000MHZ-LC-T | 1

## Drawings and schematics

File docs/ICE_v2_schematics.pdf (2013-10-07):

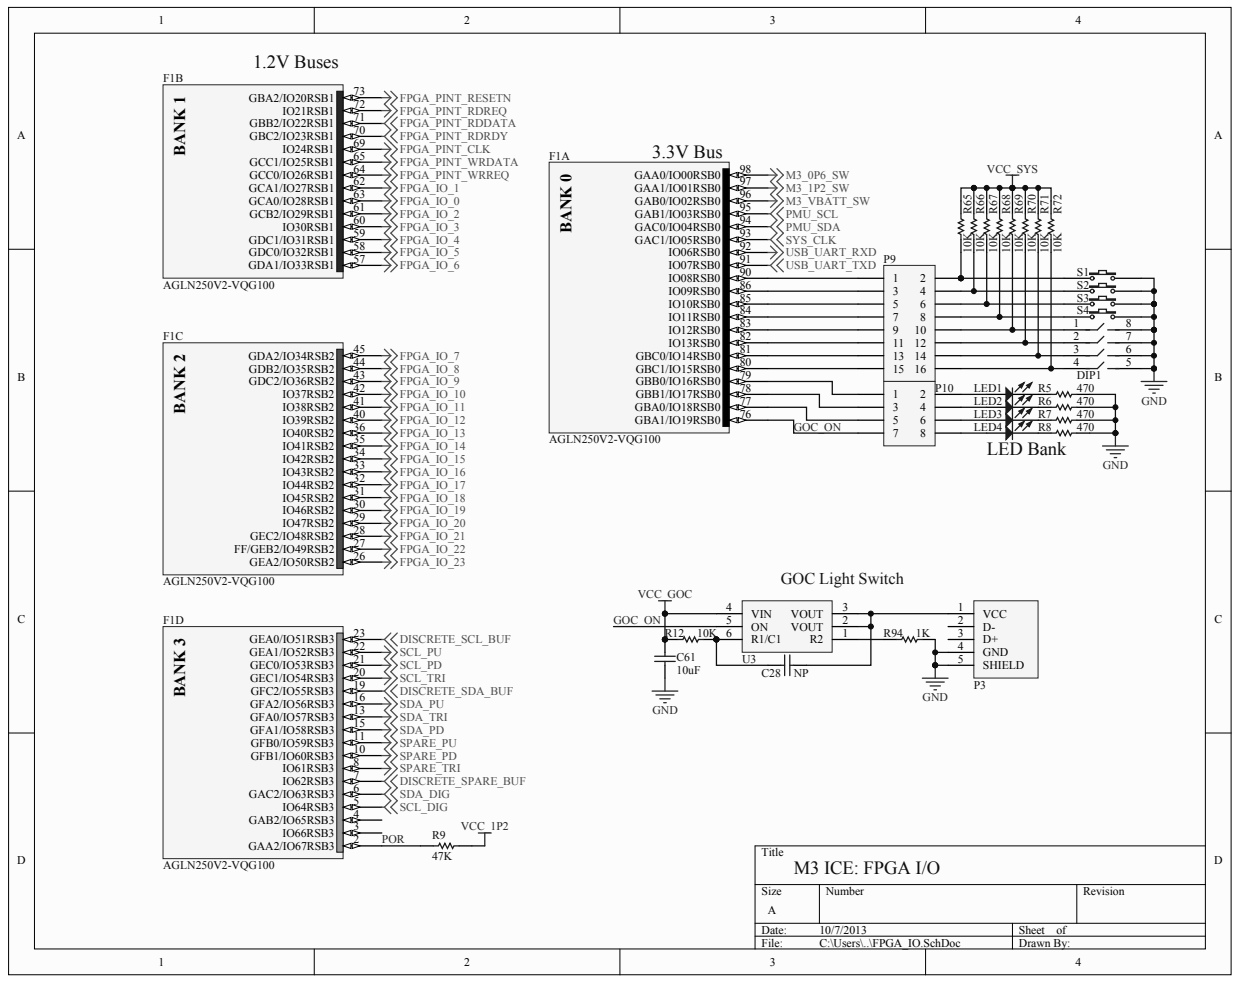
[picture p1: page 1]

S2
S3
S4

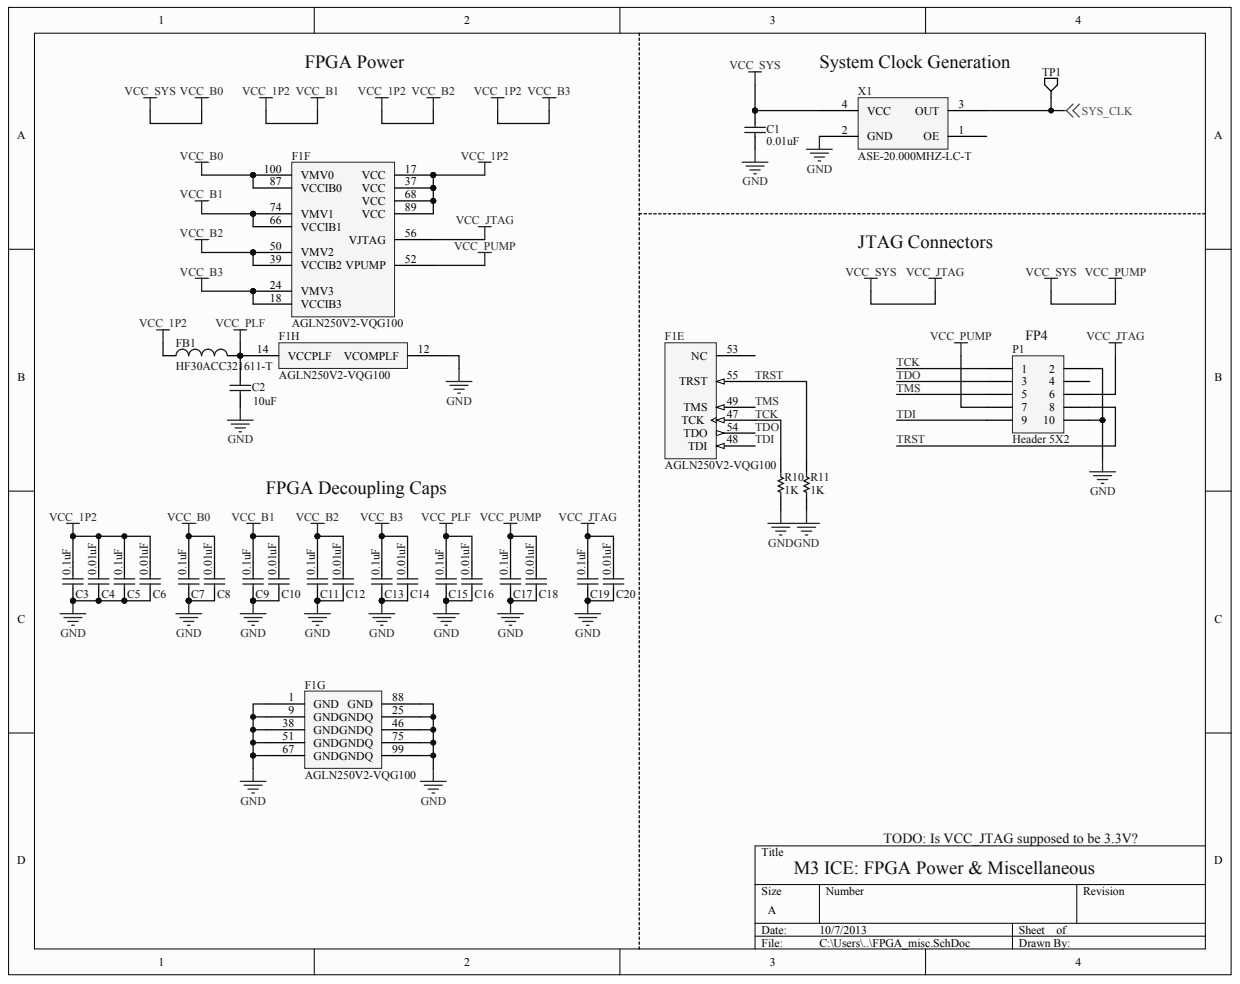
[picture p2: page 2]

TODO: Is VCC_JTAG supposed to be 3.3V?

Title
M3 ICE: FPGA Power & Miscellaneous

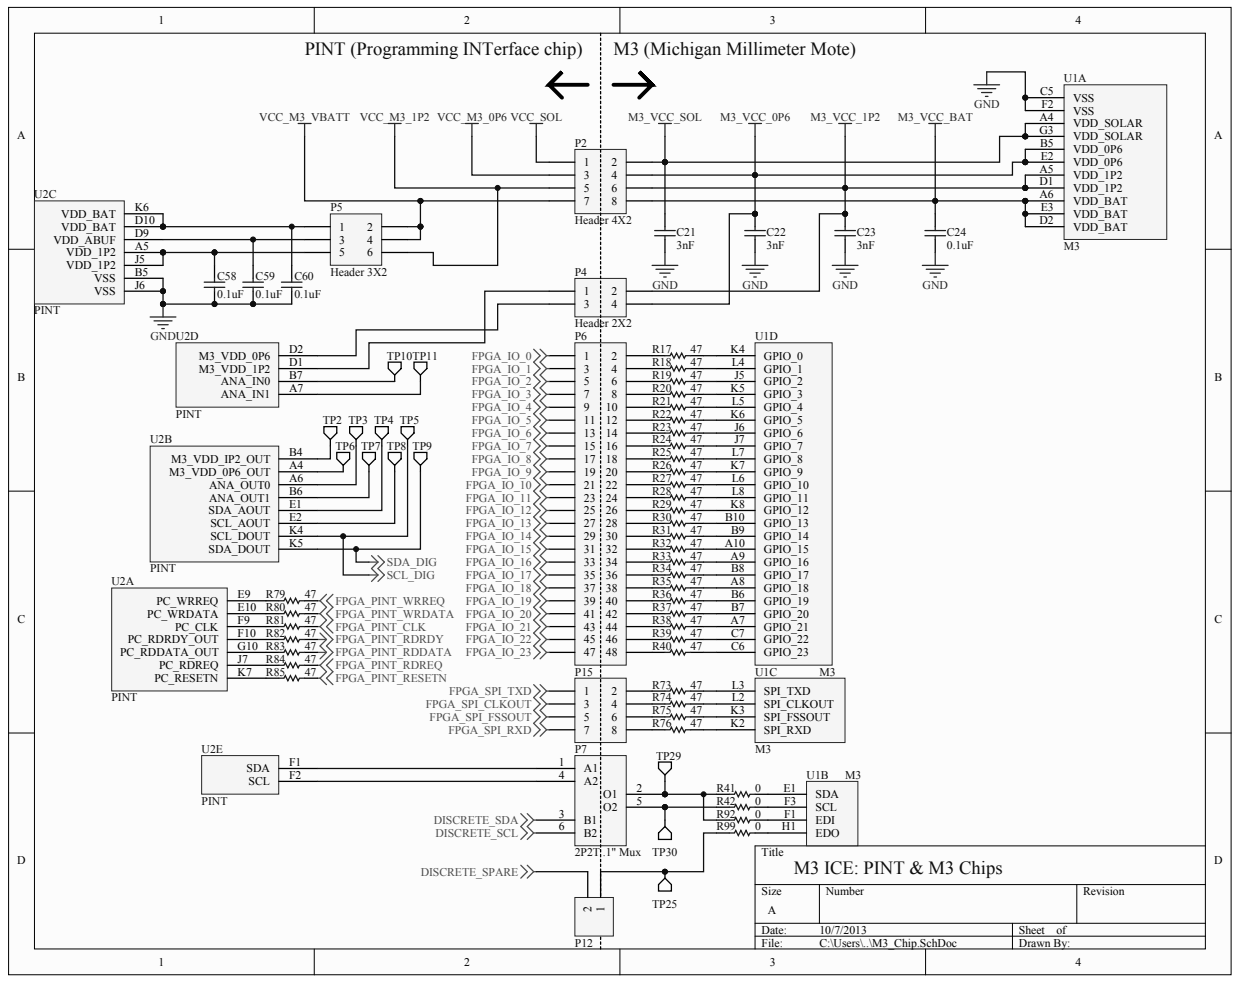
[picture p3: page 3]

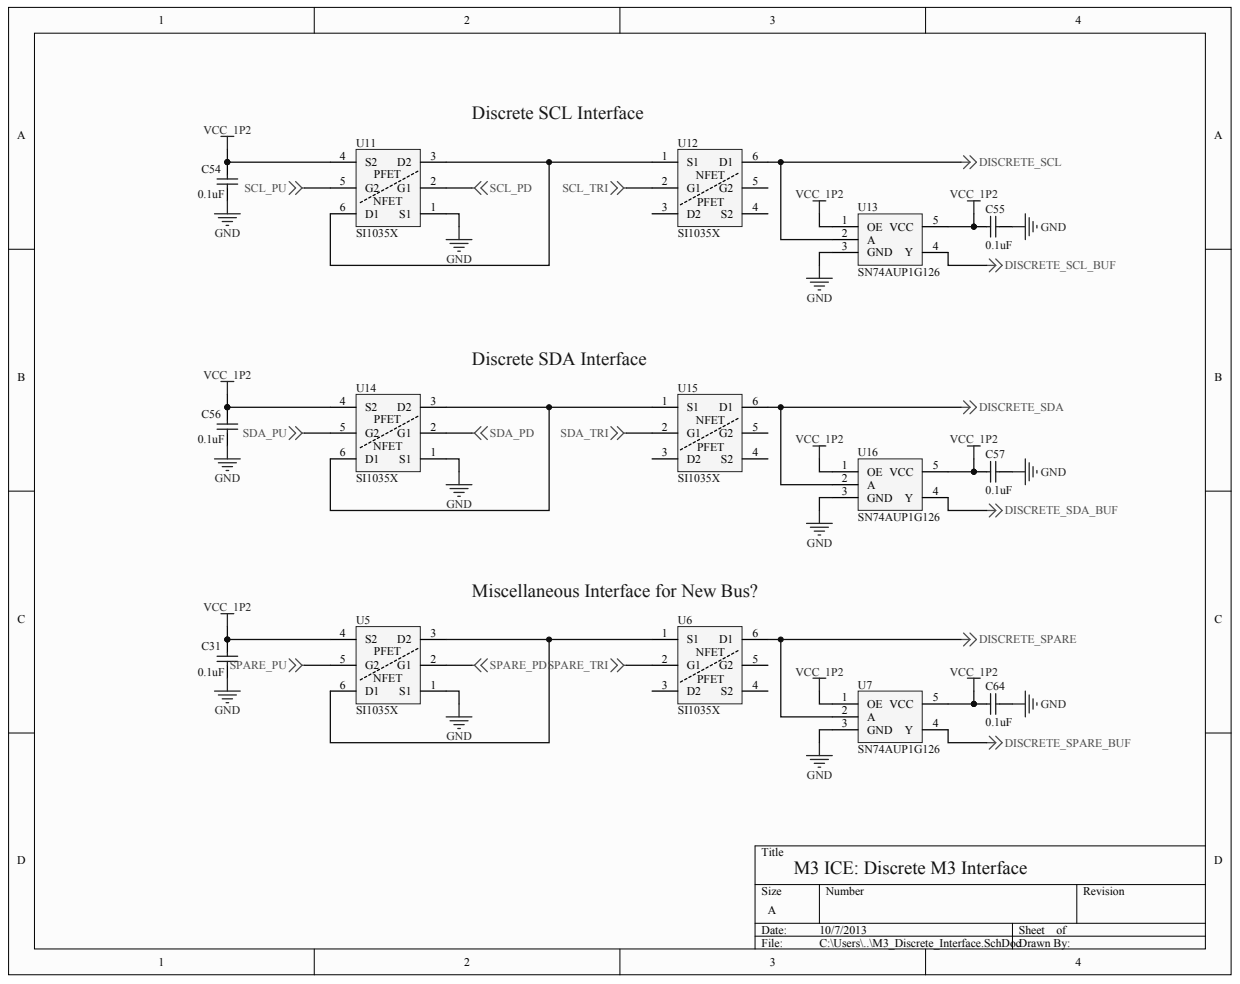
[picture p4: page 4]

Miscellaneous Interface for New Bus?

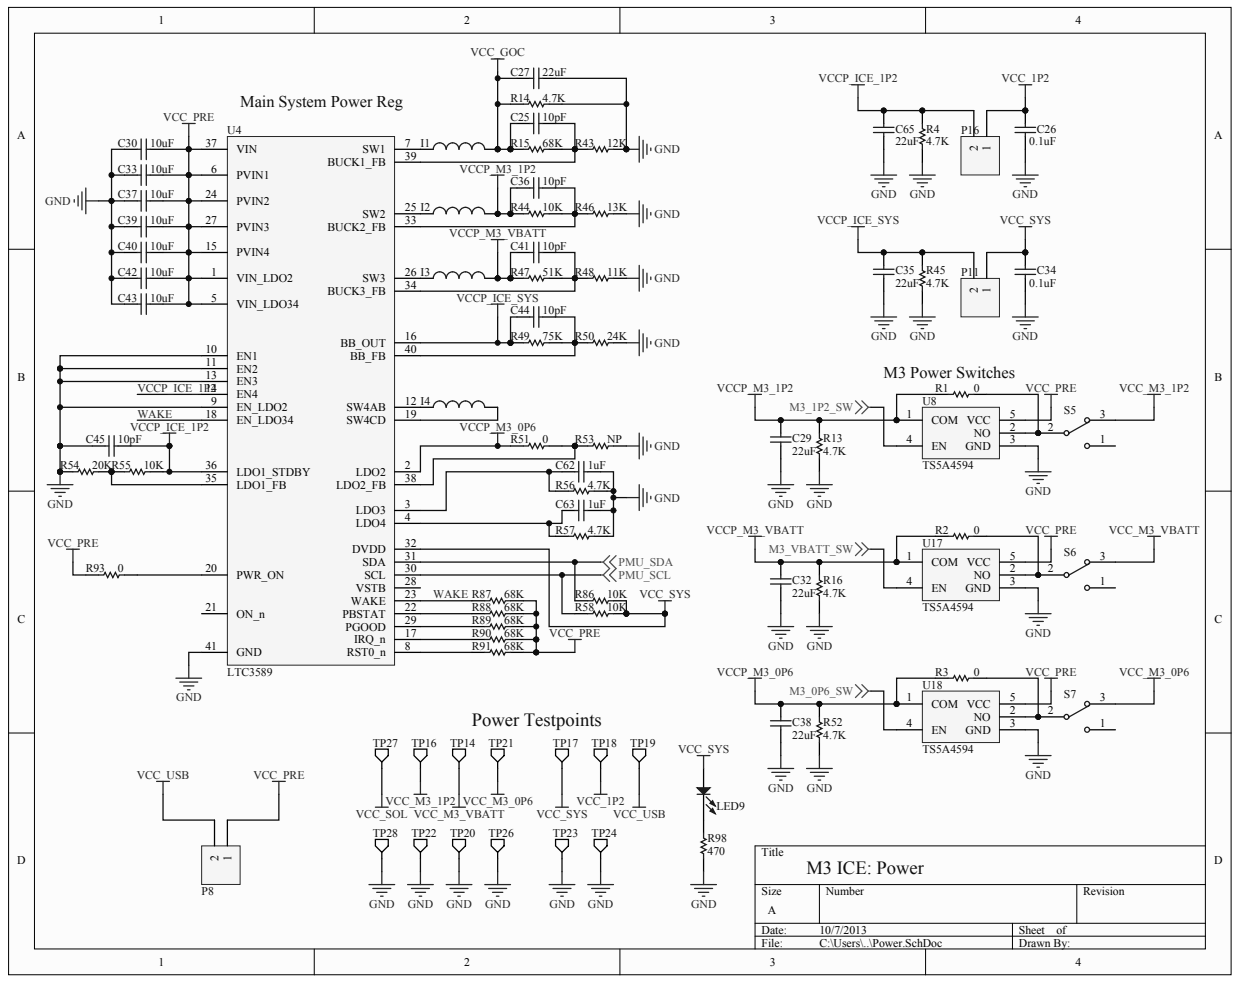
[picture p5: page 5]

Main System Power Reg

PVIN2 24

PVIN3 27
PVIN4 15 | VC CP_M3_VBATT

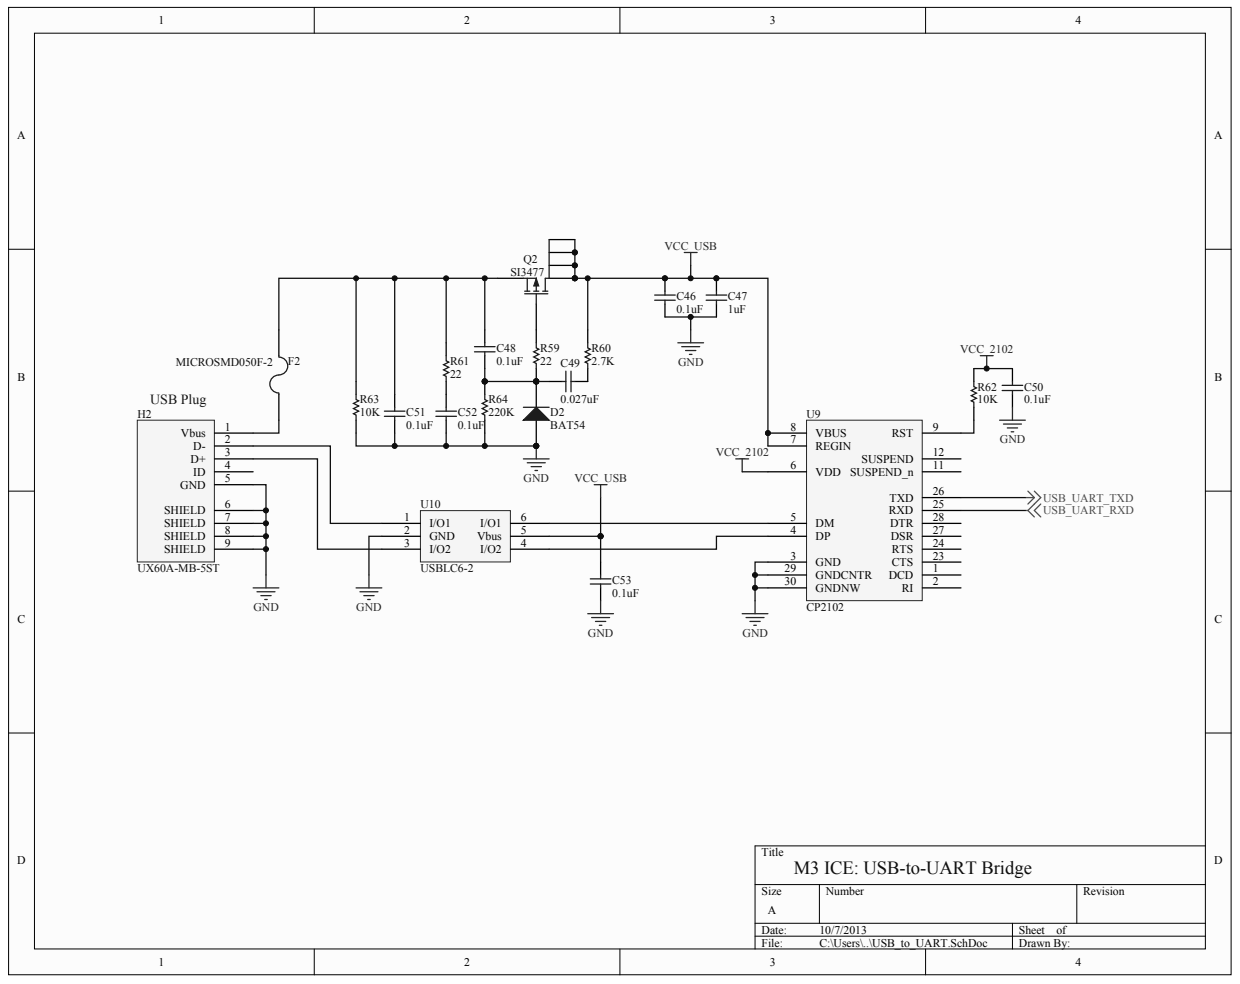
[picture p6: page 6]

3 | VC C_USB

GNDCNTR 29
GNDNW 30

Title
M3 ICE: USB-to-UART Bridg

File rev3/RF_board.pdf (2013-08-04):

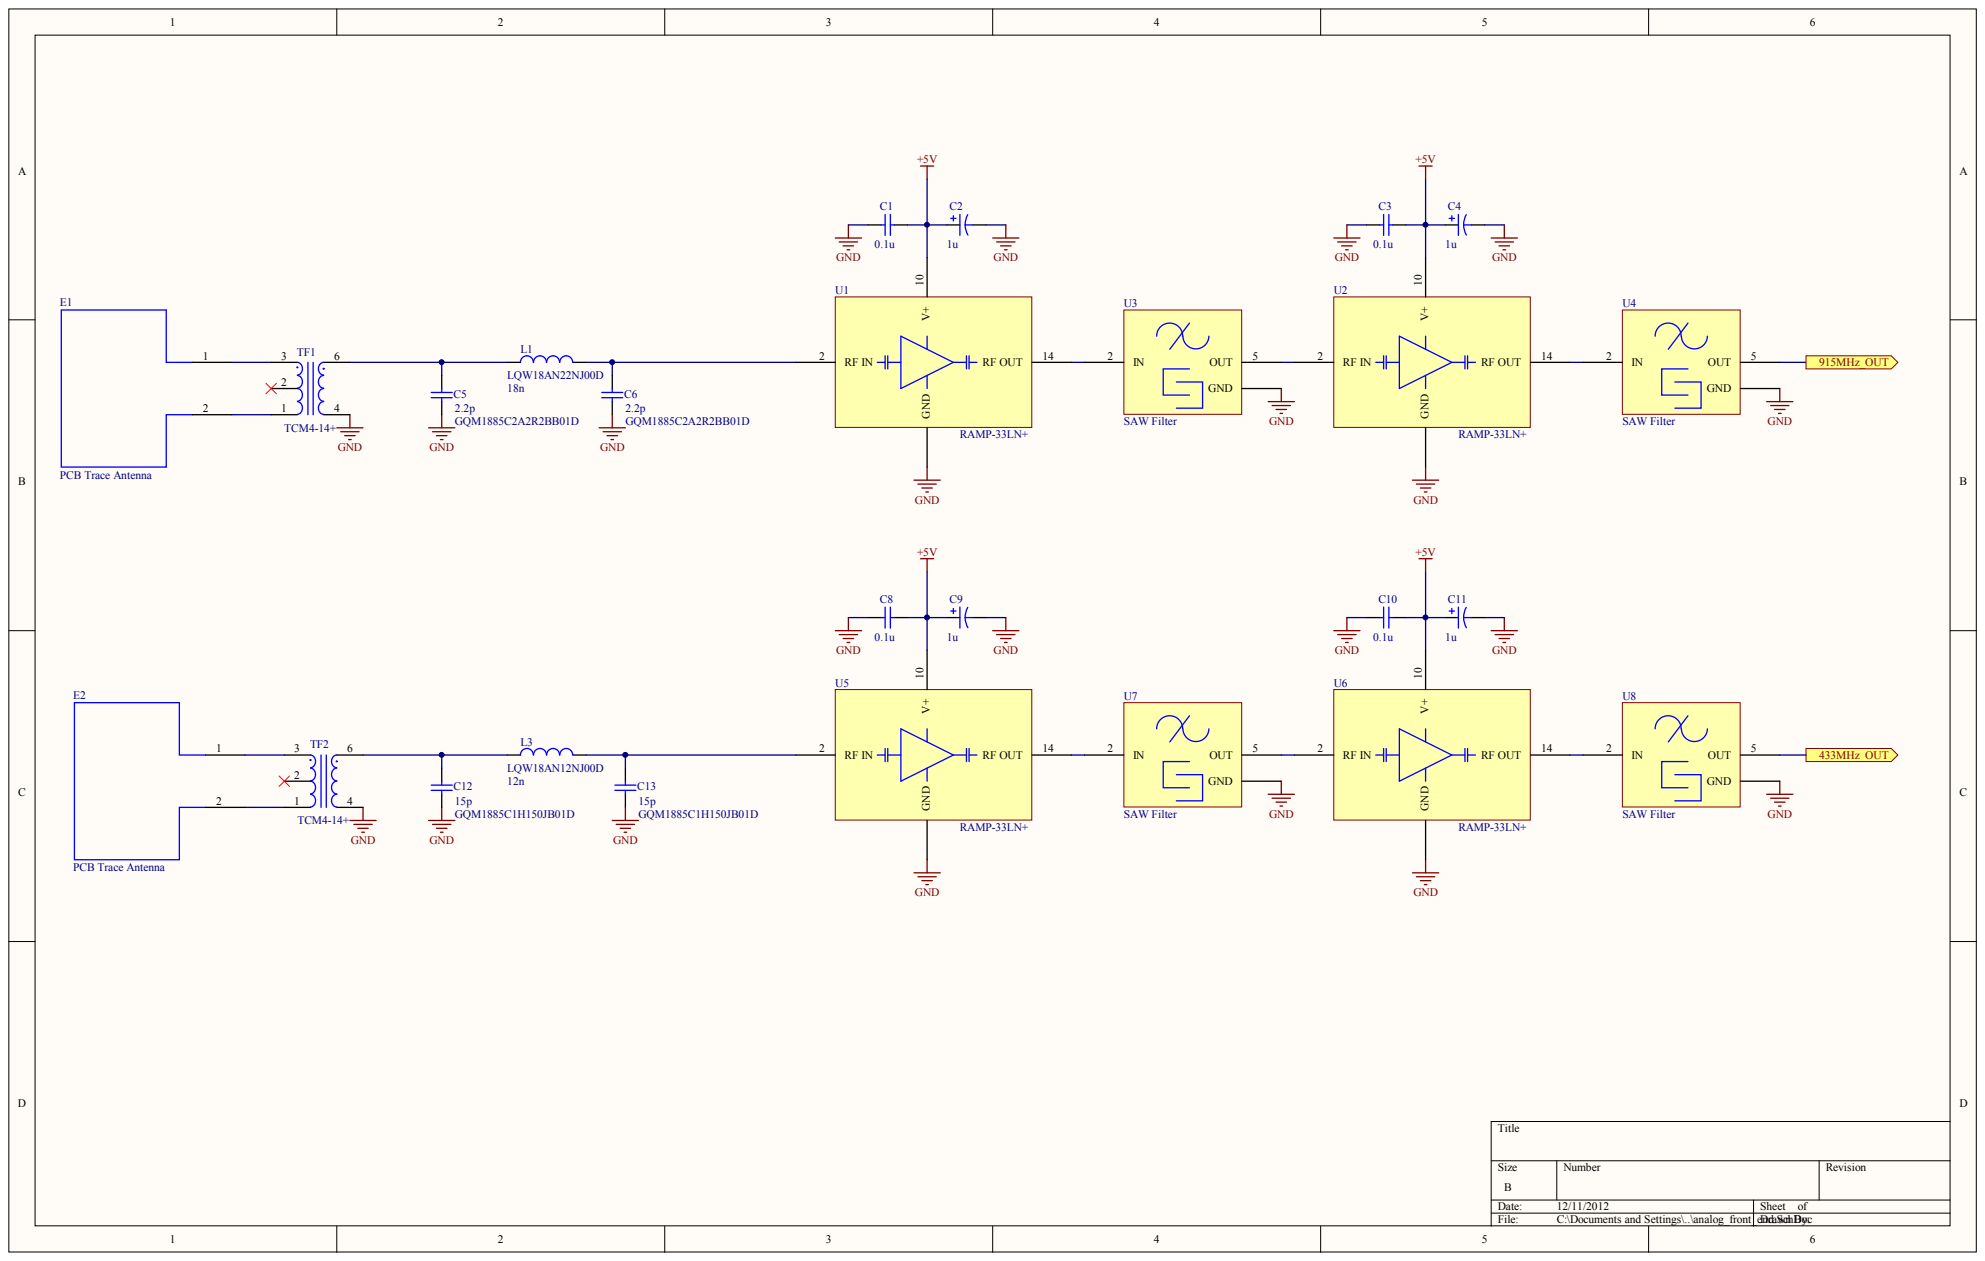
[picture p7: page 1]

Size B | Number | Revision

Date: 12/11/2012 | Sheet of
File: C:\Documents and Settings\..\analog_front_end. DraSwcn hDoBy:c

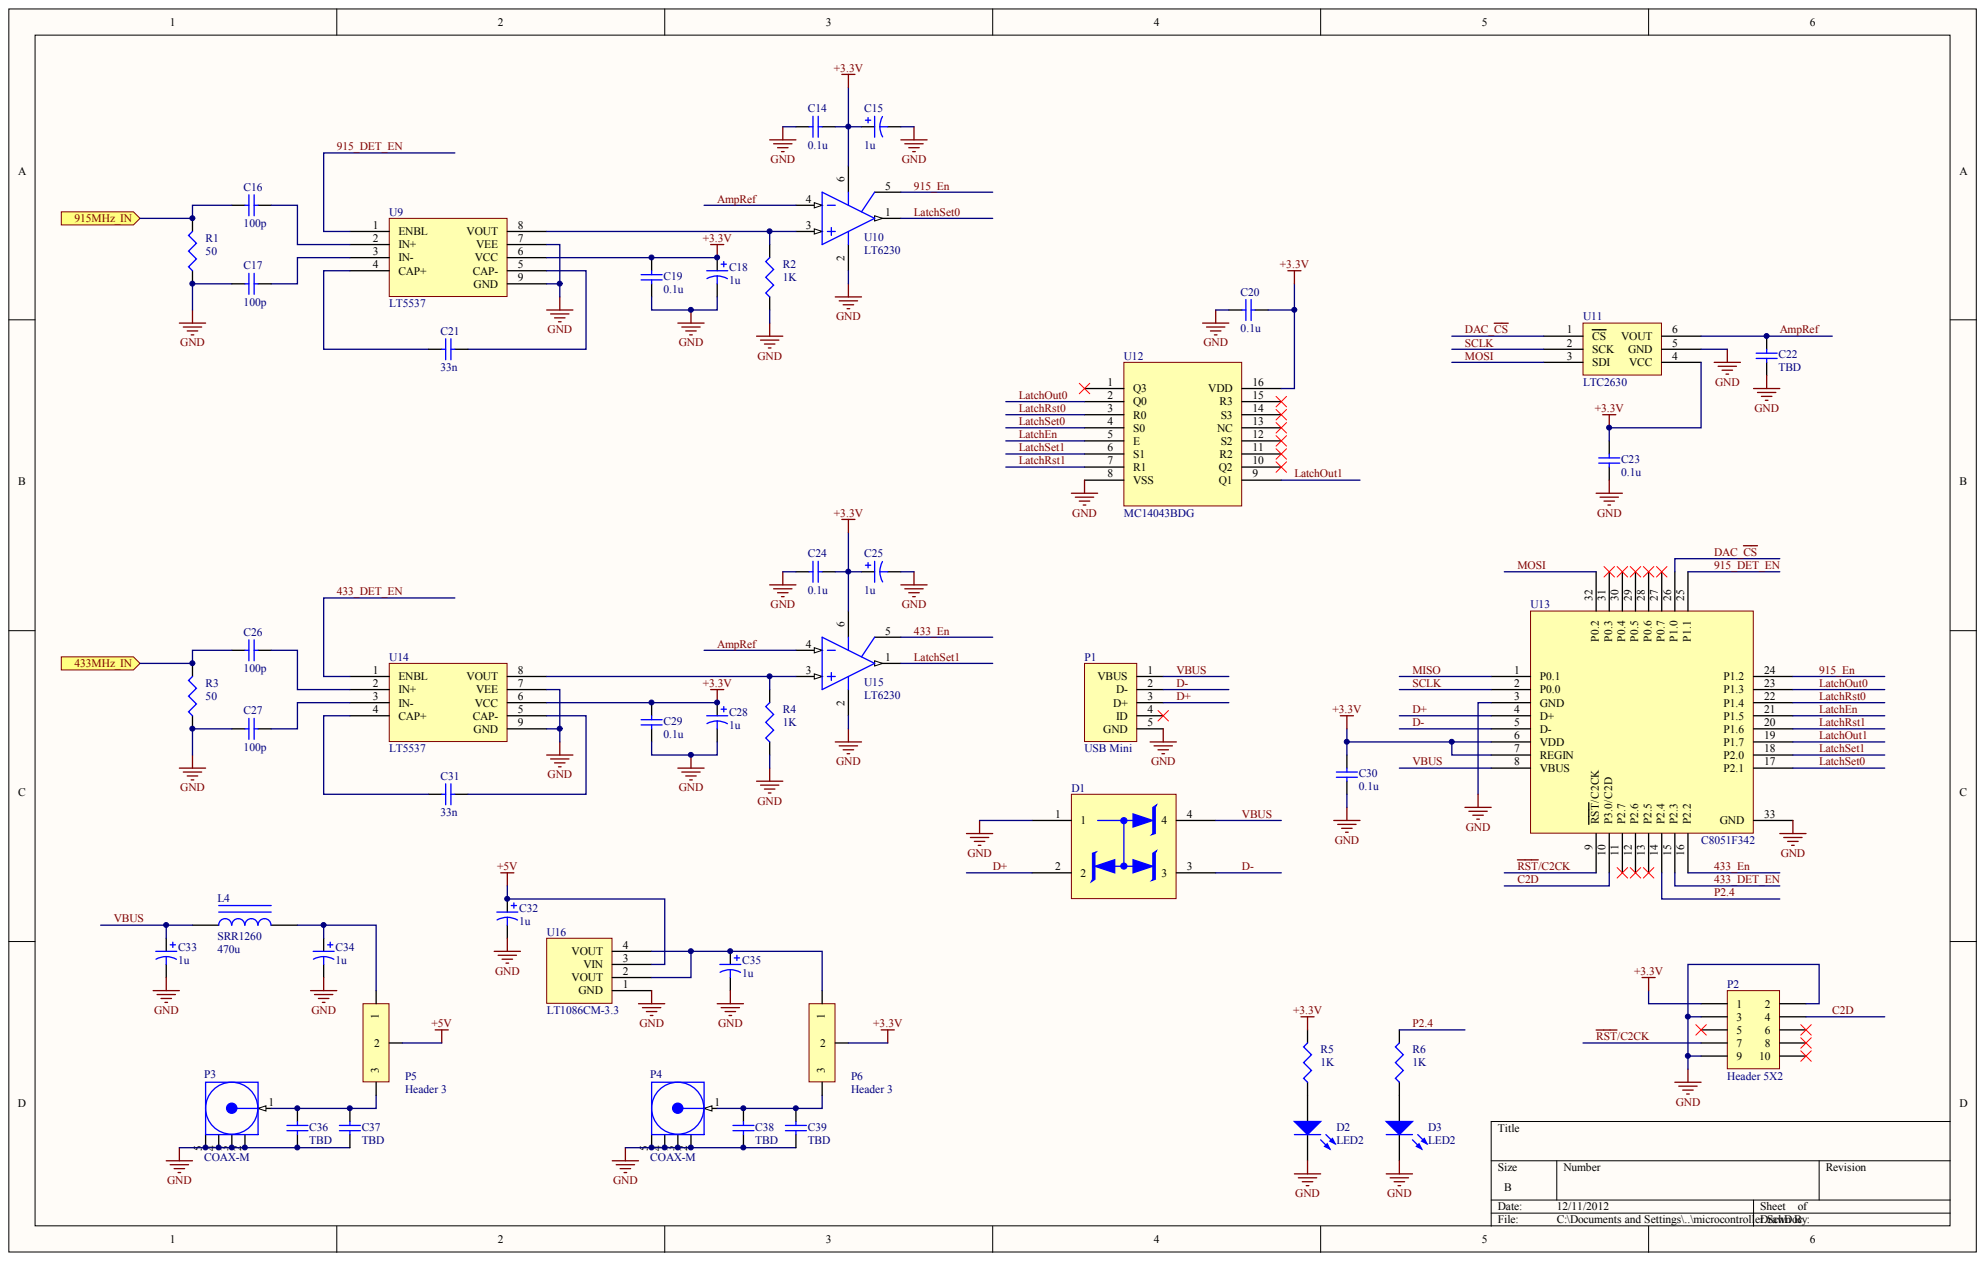
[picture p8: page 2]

ENBL 1
IN+ 2 | +3.3V

Size B | Number | Revision

Date: 12/11/2012 | Sheet of
File: C:\Documents and Settings\..\microcontroller.DScrawhDon Bcy:

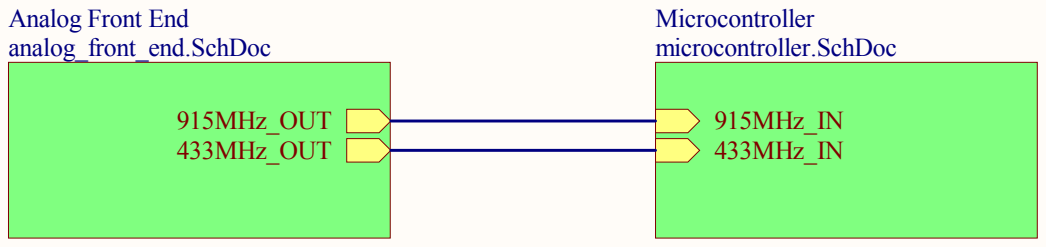
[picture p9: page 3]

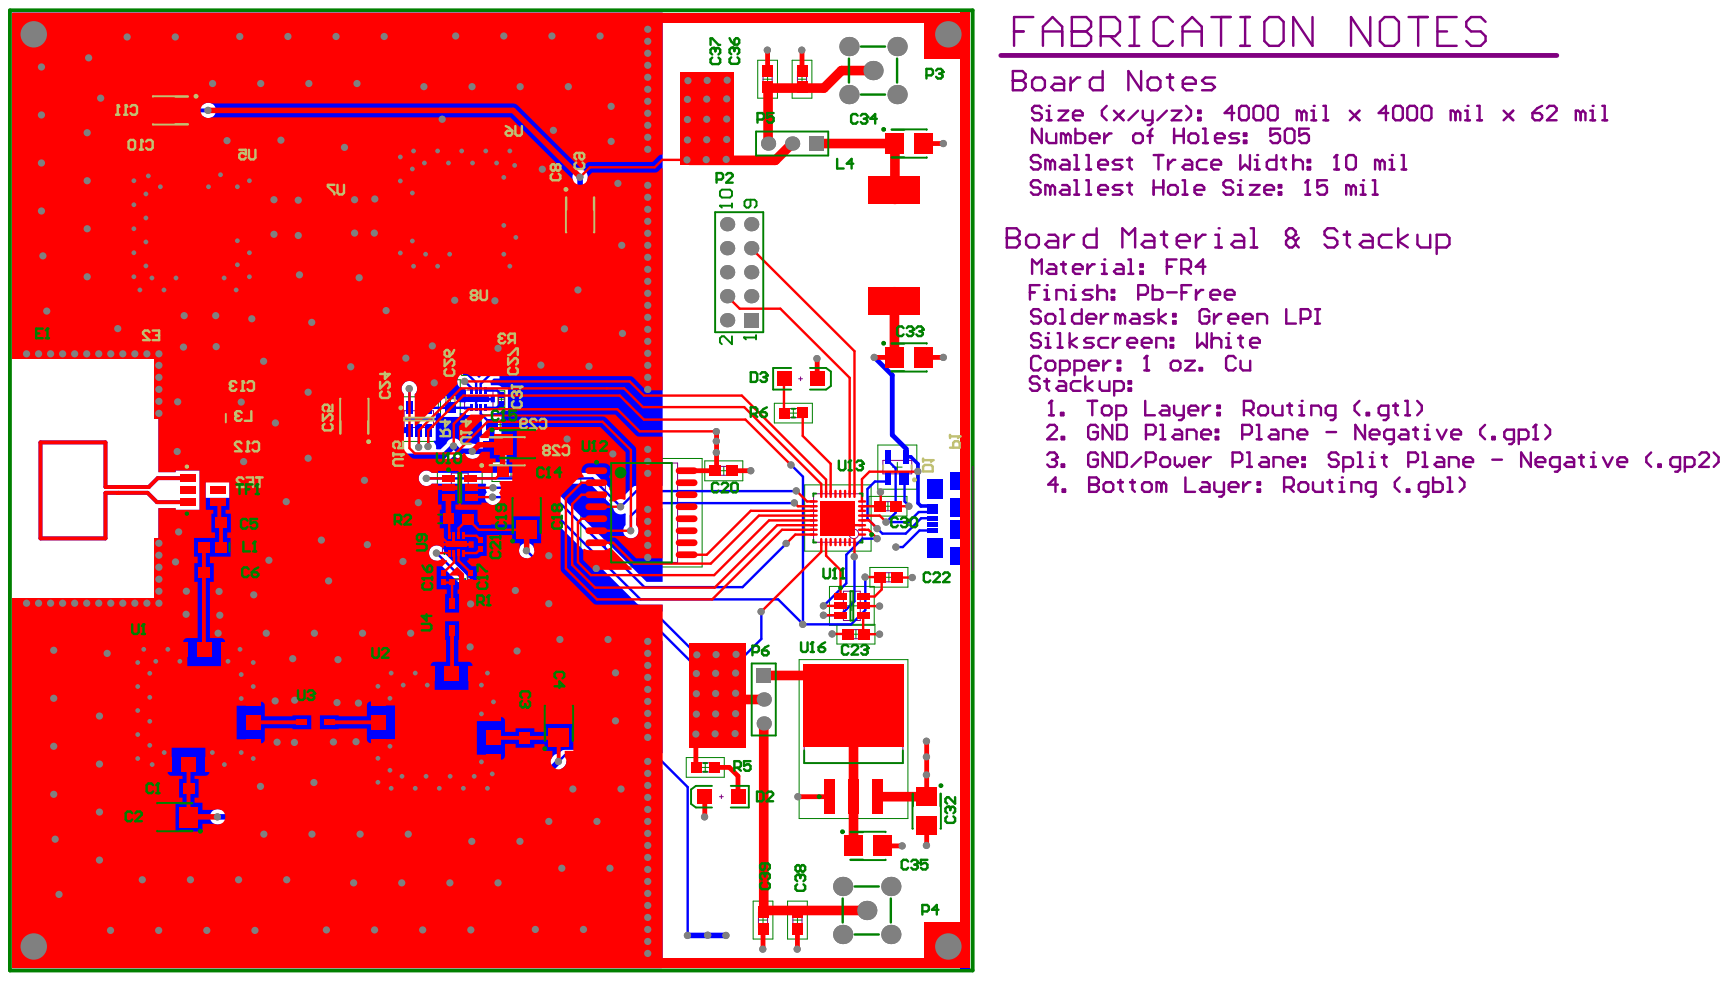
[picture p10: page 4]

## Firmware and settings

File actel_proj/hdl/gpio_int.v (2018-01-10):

`include "include/ice_def.v"

module gpio_int(clk, reset, GPIO, gpio_level, gpio_direction, gpio_int_enable, sl_data, sl_addr, sl_tail, sl_latch_tail, sl_arb_request, sl_arb_grant, global_counter, incr_ctr);
parameter GPIO_WIDTH=24;

input clk;
input reset;

inout [GPIO_WIDTH-1:0] GPIO;
input [GPIO_WIDTH-1:0] gpio_level;
input [GPIO_WIDTH-1:0] gpio_direction;
input [GPIO_WIDTH-1:0] gpio_int_enable;

//Slave output bus
inout [8:0] sl_data;
input [8:0] sl_addr;
inout [8:0] sl_tail;
input sl_latch_tail;
output sl_arb_request;
input sl_arb_grant;

//Global counter for 'time-tagging'
input [7:0] global_counter;
output reg incr_ctr;

reg frame_req;
reg [7:0] frame_data;
wire data_latch;
wire [8:0] mf_sl_data;
wire [8:0] mf_sl_tail;
assign sl_data = (sl_arb_grant) ? mf_sl_data : 9'bzzzzzzzzz;
assign sl_tail = (sl_arb_grant) ? mf_sl_tail : 9'bzzzzzzzzz;
message_fifo #( .DEPTH_LOG2(4)) 
mf1(
	.clk(clk),
	.rst(reset),

	.in_data(frame_data),
	.in_data_latch(data_latch),
	.in_frame_valid(frame_req),
	
	.tail(mf_sl_tail),
	.out_data_addr(sl_addr),
	.out_data(mf_sl_data),
	.out_frame_valid(sl_arb_request),
	.latch_tail(sl_latch_tail & sl_arb_grant)
);

//Logic to drive GPIOs using user-selected values (only if requested)
genvar ii;
generate
	for(ii = 0; ii < GPIO_WIDTH; ii=ii+1) begin
		assign GPIO[ii] = (gpio_direction[ii]) ? gpio_level[ii] : 1'bz;
	end
endgenerate

parameter STATE_IDLE = 0;
parameter STATE_MESSAGE0 = 1;
parameter STATE_MESSAGE1 = 2;
parameter STATE_MESSAGE2 = 3;
parameter STATE_MESSAGE3 = 4;
parameter STATE_MESSAGE4 = 5;

reg [3:0] state, next_state;
reg latch_gpio_levels, gpio_has_changed;
reg drive_id, drive_gcount, drive_len, drive_param, drive_latched_data;
assign data_latch = drive_id | drive_gcount | drive_len | drive_param | drive_latched_data;
reg [1:0] drive_ctr;
always @* begin
	next_state = state;
	latch_gpio_levels = 1'b0;
	frame_req = 1'b1;
	drive_id = 1'b0;
	drive_len = 1'b0;
	drive_param = 1'b0;
	drive_gcount = 1'b0;
	drive_latched_data = 1'b0;
	incr_ctr = 1'b0;
	
	case(state)
		STATE_IDLE: begin
			frame_req = 1'b0;
			latch_gpio_levels = 1'b1;
			if(gpio_has_changed)
				next_state = STATE_MESSAGE0;
		end
		
		STATE_MESSAGE0: begin
			drive_id = 1'b1;
			next_state = STATE_MESSAGE1;
		end
		
		STATE_MESSAGE1: begin
			drive_gcount = 1'b1;
			incr_ctr = 1'b1;
			next_state = STATE_MESSAGE2;
		end
		
		STATE_MESSAGE2: begin
			drive_len = 1'b1;
			next_state = STATE_MESSAGE3;
		end
		
		STATE_MESSAGE3: begin
			drive_param = 1'b1;
			next_state = STATE_MESSAGE4;
		end
		
		STATE_MESSAGE4: begin
			drive_latched_data = 1'b1;
			if(drive_ctr == 2)
				next_state = STATE_IDLE;
		end
	endcase
end

//Monitor for any changes to the un-driven bits
reg [GPIO_WIDTH-1:0] last_gpio_levels, last_gpio_levels_db;
integer jj;
always @* begin
	gpio_has_changed = 1'b0;
	for(jj = 0; jj < GPIO_WIDTH; jj = jj + 1) begin
		if(~gpio_direction[jj]) begin
			if((last_gpio_levels[jj] ^ last_gpio_levels_db[jj]) & gpio_int_enable[jj])
				gpio_has_changed = 1'b1;
		end
	end
	
	frame_data = 8'h67;
	if(drive_gcount) frame_data = global_counter;
	else if(drive_param) frame_data = 8'h6c;
	else if(drive_latched_data) begin
		if(drive_ctr == 0)
			frame_data = last_gpio_levels[23:16];
		else if(drive_ctr == 1)
			frame_data = last_gpio_levels[15:8];
		else
			frame_data = last_gpio_levels[7:0];
	end
end

always @(posedge clk) begin
	if(reset) begin
		state <= `SD STATE_IDLE;
	end else begin
		state <= `SD next_state;
		//The latch_gpio_levels keeps track of the last-communicated GPIO levels for the analysis of any changes
		//TODO: Probably needs this debouncing logic, eh?
		if(latch_gpio_levels) begin
			last_gpio_levels_db <= `SD GPIO;
			last_gpio_levels <= `SD last_gpio_levels_db;
		end
		
		if(drive_latched_data)
			drive_ctr <= `SD drive_ctr + 1;
		else
			drive_ctr <= `SD 0;
	end
end

endmodule

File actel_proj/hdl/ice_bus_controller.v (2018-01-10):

`include "include/ice_def.v"

module ice_bus_controller(clk, rst, rx_char, rx_char_valid, tx_char, tx_char_valid, tx_char_ready, generate_nak, evt_id, ma_data, ma_addr, ma_data_valid, ma_frame_valid, sl_overflow, sl_addr, sl_tail, sl_latch_tail, sl_data, sl_arb_request, sl_arb_grant);
parameter NUM_DEV=2;

input clk;
input rst;

//Interface to UART (or other character device)
input [7:0] rx_char;
input rx_char_valid;
output [7:0] tx_char;
output reg tx_char_valid;
input tx_char_ready;

//Immediate NAKs have their own controller =)
output reg generate_nak;
output reg [7:0] evt_id;

//Master-driven bus (data & control)
output [7:0] ma_data;
output reg [7:0] ma_addr;
output reg ma_data_valid;
output reg ma_frame_valid;
input sl_overflow;

//Bus controller outputs (data & control)
output [8:0] sl_addr;
input [8:0] sl_tail;
output reg sl_latch_tail;
input [8:0] sl_data;
input [NUM_DEV-1:0] sl_arb_request;
output [NUM_DEV-1:0] sl_arb_grant;

//For now the master bus is just a direct connection to the UART rx character bus.  May always be this way??
assign ma_data = rx_char;

wire pri_en, pri_granted;
wire pri_latch;
priority_select #(NUM_DEV) pri1(
	.clk(clk),
	.rst(rst),
	.enable(pri_en),
	.latch(pri_latch),
	
	.requests(sl_arb_request),
	.grants(sl_arb_grant),
	.granted(pri_granted)
);

reg record_addr, record_evt_id;
reg byte_counter_incr, byte_counter_decr, byte_counter_reset, set_byte_counter;
reg shift_in_pyld_len;
reg [7:0] byte_counter;
reg [7:0] payload_len;

//Bus controller RX state machine
parameter STATE_RX_IDLE = 0;
parameter STATE_RX_ID = 1;
parameter STATE_RX_LEN = 2;
parameter STATE_RX_PYLD = 3;
parameter STATE_RX_OVERFLOW = 4;
reg [3:0] state, next_state;

always @* begin
	next_state = state;
	record_addr = 1'b0;
	record_evt_id = 1'b0;
	byte_counter_incr = 1'b0;
	byte_counter_decr = 1'b0;
	byte_counter_reset = 1'b0;
	shift_in_pyld_len = 1'b0;
	ma_data_valid = 1'b0;
	ma_frame_valid = 1'b0;
	set_byte_counter = 1'b0;
	generate_nak = 1'b0;
	
	case(state)
		STATE_RX_IDLE: begin
			record_addr = 1'b1;
			ma_frame_valid = rx_char_valid;
			byte_counter_reset = 1'b1;
			if(rx_char_valid)
				next_state = STATE_RX_ID;
		end
		
		STATE_RX_ID: begin
			ma_frame_valid = 1'b1;
			ma_data_valid = rx_char_valid;
			record_evt_id = 1'b1;
			if(rx_char_valid)
				next_state = STATE_RX_LEN;
		end
		
		STATE_RX_LEN: begin
			ma_frame_valid = 1'b1;
			ma_data_valid = rx_char_valid;
			shift_in_pyld_len = rx_char_valid;
			if(rx_char_valid) begin
				byte_counter_reset = 1'b1;
				next_state = STATE_RX_PYLD;
			end
		end
		
		STATE_RX_PYLD: begin
			ma_frame_valid = 1'b1;
			ma_data_valid = rx_char_valid;
			byte_counter_incr = rx_char_valid;
			if(byte_counter == payload_len)
				next_state = STATE_RX_IDLE;
			else if(sl_overflow)
				next_state = STATE_RX_OVERFLOW;
		end
		
		STATE_RX_OVERFLOW: begin
			generate_nak = 1'b1;
			next_state = STATE_RX_IDLE;
		end
	endcase
end

always @(posedge clk) begin
	
	if(rst) begin
		state <= `SD STATE_RX_IDLE;
		byte_counter <= `SD 16'd0;
	end else begin
		state <= `SD next_state;
			
		if(shift_in_pyld_len) begin
			payload_len <= `SD rx_char;
		end
		if(record_addr)
			ma_addr <= `SD rx_char;
		if(record_evt_id)
			evt_id <= `SD rx_char;

		//Byte counter keeps track of packets up to 65535 bytes in size
		if(byte_counter_reset)
			byte_counter <= `SD 16'd0;
		else if(byte_counter_incr)
			byte_counter <= `SD byte_counter + 16'd1;
	end
end

//TX state machine...
//assign tx_char_valid = tx_char_ready & pri_granted;
assign pri_latch = ~pri_granted;
assign pri_en = 1'b1;

reg [8:0] sl_addr_offset;
reg [7:0] sl_addr_offset_save;
assign sl_addr = sl_tail + sl_addr_offset;

parameter STATE_TX_IDLE = 0;
parameter STATE_TX_GETLEN = 1;
parameter STATE_TX_HEADER_PRE = 2;
parameter STATE_TX_HEADER = 3;
parameter STATE_TX_LEN = 4;
parameter STATE_TX_PAYLOAD = 5;
parameter STATE_TX_LATCH_TAIL = 6;

reg [3:0] tx_state, next_tx_state;
reg save_offset;
reg tx_len;
reg addr_offset_clear, addr_offset_incr;

assign tx_char = (tx_len) ? sl_addr_offset_save[7:0] : sl_data[7:0];

always @(posedge clk) begin
	if(rst) begin
		tx_state <= `SD STATE_TX_IDLE;
		sl_addr_offset <= `SD 0;
	end else begin
		tx_state <= `SD next_tx_state;
		if(addr_offset_clear)
			sl_addr_offset <= `SD 0;
		else if(addr_offset_incr)
			sl_addr_offset <= `SD sl_addr_offset + 1;
		if(save_offset)
			sl_addr_offset_save <= `SD sl_addr_offset - 4;
	end
end

always @* begin
	next_tx_state = tx_state;
	addr_offset_clear = 1'b0;
	addr_offset_incr = 1'b0;
	save_offset = 1'b0;
	tx_char_valid = 1'b0;
	tx_len = 1'b0;
	sl_latch_tail = 1'b0;
	case(tx_state)
		STATE_TX_IDLE: begin
			addr_offset_clear = 1'b1;
			if(pri_granted) begin
				next_tx_state = STATE_TX_GETLEN;
			end
		end

		STATE_TX_GETLEN: begin
			addr_offset_incr = 1'b1;
			if(sl_data[8]) begin
				save_offset = 1'b1;
				addr_offset_clear = 1'b1;
				next_tx_state = STATE_TX_HEADER_PRE;
			end
		end

		STATE_TX_HEADER_PRE: begin
			//Have to wait one cycle before txing anything to
			//allow RAM to sync
			next_tx_state = STATE_TX_HEADER;
		end

		STATE_TX_HEADER: begin
			addr_offset_incr = tx_char_ready;
			tx_char_valid = tx_char_ready;
			if(sl_addr_offset == 2)
				next_tx_state = STATE_TX_LEN;
		end

		STATE_TX_LEN: begin
			addr_offset_incr = tx_char_ready;
			tx_char_valid = tx_char_ready;
			tx_len = 1'b1;
			if(tx_char_ready)
				next_tx_state = STATE_TX_PAYLOAD;
		end

		STATE_TX_PAYLOAD: begin
			addr_offset_incr = tx_char_ready;
			tx_char_valid = tx_char_ready;
			if(sl_data[8]) begin
				addr_offset_incr = 1'b1;
				next_tx_state = STATE_TX_LATCH_TAIL;
			end
		end

		STATE_TX_LATCH_TAIL: begin
			sl_latch_tail = 1'b1;
			next_tx_state = STATE_TX_IDLE;
		end
	endcase
end

endmodule

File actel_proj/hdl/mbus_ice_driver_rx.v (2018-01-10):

`include "include/ice_def.v"

module mbus_ice_driver_rx (
    input               clk,
    input               reset,

    //stuff from mbus  
    input [31:0]        mbus_rx_addr,
	input [31:0]        mbus_rx_data,
	input               mbus_rx_req, 
	output reg          mbus_rx_ack,
	input               mbus_rx_broadcast,
	input               mbus_rx_fail,
	input               mbus_rx_pend,
	input [1:0]         mbus_rx_control_bits,
    
    output reg          buffer_request,
    input               buffer_grant,
    output reg [7:0]    buffer_data,
    output reg          buffer_valid,

    input [7:0]         global_counter,
	output reg          global_counter_inc
    );

parameter RX_ST_IDLE        = 0;
parameter RX_ST_CODE        = 1;
parameter RX_ST_EID         = 2;
parameter RX_ST_DUMMY       = 3;
parameter RX_ST_ADDR0       = 4;
parameter RX_ST_ADDR1       = 5;
parameter RX_ST_ADDR2       = 6;
parameter RX_ST_ADDR3       = 7;
parameter RX_ST_DATA0       = 8;
parameter RX_ST_DATA1       = 9;
parameter RX_ST_DATA2       = 10; //a
parameter RX_ST_DATA3       = 11; //b
parameter RX_ST_PEND        = 12; //c
parameter RX_ST_PEND_ACK    = 13; //d
parameter RX_ST_PEND_WAIT   = 14; //e
parameter RX_ST_CTRL_BITS   = 15; //f
parameter RX_ST_END_ACK     = 16; //10
parameter RX_ST_SZ = $clog2(RX_ST_END_ACK+1);

reg [RX_ST_SZ-1:0]      rx_state /* synthesis syn_encoding="gray" */;
reg [RX_ST_SZ-1:0]      rx_next_state;

always @(posedge clk) begin
    if (reset) begin
        rx_state <= `SD RX_ST_IDLE;
    end else begin
        rx_state <= `SD rx_next_state;
    end
end

always @* begin
    rx_next_state = rx_state;
    buffer_request = 0;
    buffer_data = 8'hz;
    buffer_valid = 0;
    global_counter_inc = 0;
    mbus_rx_ack = 0;

    case(rx_state) 
        RX_ST_IDLE: begin 
            if (mbus_rx_fail == 1) begin
                rx_next_state = RX_ST_END_ACK;
            end else if (mbus_rx_req == 1) begin
                rx_next_state = RX_ST_CODE;
            end
        end

        RX_ST_CODE: begin 
            buffer_request = 1;
            buffer_data = 8'h62;
            //might need to wait
            if (buffer_grant == 1) 
                rx_next_state = RX_ST_EID;
        end

        RX_ST_EID: begin 
            buffer_request = 1;
            buffer_data = global_counter;
            buffer_valid = 1;
            global_counter_inc = 1;
            rx_next_state = RX_ST_DUMMY;
        end

        RX_ST_DUMMY: begin 
            buffer_request = 1;
            //just write 0 here, will get updated later
            buffer_data = 8'h0; 
            buffer_valid = 1;
            rx_next_state = RX_ST_ADDR0;
        end

        RX_ST_ADDR0: begin 
            buffer_request = 1;
            buffer_data = mbus_rx_addr[31:24];
            buffer_valid = 1;
            rx_next_state = RX_ST_ADDR1;
        end
        
        RX_ST_ADDR1: begin 
            buffer_request = 1;
            buffer_data = mbus_rx_addr[23:16];
            buffer_valid = 1;
            rx_next_state = RX_ST_ADDR2;
        end

        RX_ST_ADDR2: begin 
            buffer_request = 1;
            buffer_data = mbus_rx_addr[15:8];
            buffer_valid = 1;
            rx_next_state = RX_ST_ADDR3;
        end

        RX_ST_ADDR3: begin 
            buffer_request = 1;
            buffer_data = mbus_rx_addr[7:0];
            buffer_valid = 1;
            rx_next_state = RX_ST_DATA0;
        end

        RX_ST_DATA0: begin 
            buffer_request = 1;
            buffer_data = mbus_rx_data[31:24];
            buffer_valid = 1;
            rx_next_state = RX_ST_DATA1;
        end

        RX_ST_DATA1: begin 
            buffer_request = 1;
            buffer_data = mbus_rx_data[23:16];
            buffer_valid = 1;
            rx_next_state = RX_ST_DATA2;
        end

        RX_ST_DATA2: begin 
            buffer_request = 1;
            buffer_data = mbus_rx_data[15:8];
            buffer_valid = 1;
            rx_next_state = RX_ST_DATA3;

        end

        RX_ST_DATA3: begin 
            buffer_request = 1;
            buffer_data = mbus_rx_data[7:0];
            buffer_valid = 1;
            rx_next_state = RX_ST_PEND;
        end
        
        RX_ST_PEND: begin
            buffer_request = 1;
            if (mbus_rx_pend == 1)
                rx_next_state = RX_ST_PEND_ACK;
            else
                rx_next_state = RX_ST_CTRL_BITS;
        end

        RX_ST_PEND_ACK: begin
            buffer_request = 1; 
            mbus_rx_ack = 1;
            if (mbus_rx_req == 0)
                rx_next_state = RX_ST_PEND_WAIT;
        end

        RX_ST_PEND_WAIT: begin
            buffer_request = 1; //hold the buffer until we get another packet
            if (mbus_rx_req == 1)
                rx_next_state = RX_ST_DATA0;
        end

        RX_ST_CTRL_BITS: begin 
            buffer_request = 1;
            buffer_data = {5'b00000, mbus_rx_broadcast, mbus_rx_control_bits};
            buffer_valid = 1;
            rx_next_state = RX_ST_END_ACK;
        end

        RX_ST_END_ACK: begin
            mbus_rx_ack = 1;
            //need to wait until either req or fail falls
            if(( mbus_rx_req == 0) && (mbus_rx_fail == 0))
                rx_next_state = RX_ST_IDLE; 
        end

        default: begin
            rx_next_state = rx_state;
            buffer_request = 0;
            buffer_data = 8'hz;
            buffer_valid = 0;
            global_counter_inc = 0;
            mbus_rx_ack = 0;
        end
        
    endcase
end

endmodule

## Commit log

2012-10-07 initial commit of M3 ICE board to shed_svn
    [FPGA_IO.SchDoc, FPGA_misc.SchDoc, M3 ICE.PcbDoc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]
2012-10-09 Routing done for M3 ICE Board
    [FPGA_IO.SchDoc, FPGA_misc.SchDoc, M3 ICE.PcbDoc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]
2012-10-12 Changes suggested by Yoonmyung & Prabal
    [FPGA_IO.SchDoc, FPGA_misc.SchDoc, M3 ICE.PcbDoc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]
2012-10-15 final design files for board sent out for fabrication
    [M3 ICE.PcbDoc, M3 ICE.PrjPcb]
2012-10-15 Updated libraries and schematic components to include distributor (Digikey) part numbers
    [FPGA_IO.SchDoc, FPGA_misc.SchDoc, M3 ICE.PrjPcb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]
2012-11-01 adding initial verilog files for M3 ICE board. Add them to a project by linking to created Libero project instead of importing them...
2012-11-05 adding initial prototype controller...
2012-11-06 fixed compilation errors, and tidying up the old i2c interface
2012-11-12 adding a different interface which doesn't have to deal with bridging two I2C buses together
2012-11-16 fixed UART so that the FPGA TX's the correct frame data
2012-11-18 adding proposed updates to make ACKs to I2C transactions user-selectable. Still need to move to shared bus architecture though because this is getting a little ridiculous...
2012-11-19 adding PoR circuit to add power-on-reset functionality to current ICE design (requires a little resistor hacking on v1 board in order to get it to work...)
2012-11-20 PoR circuit added and tested
2012-11-20 adding next revision of M3 ICE board to fix the problems and add additional features to the rev1 board
    [FPGA_IO.SchDoc, FPGA_misc.SchDoc, M3 ICE.PcbDoc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]
2012-11-20 done with schematic updates for rev1.1. Now for PCB layout changes
    [FPGA_IO.SchDoc, M3 ICE.PcbDoc, M3.PcbLib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]
2012-11-21 added PoR circuitry to top-level instance. Also added priority selector for eventual bus arbitration logic
2012-11-25 candidate v1.1 board - doesn't include any of Pat's proposed GPIO changes
    [M3 ICE.PcbDoc, M3 ICE.PrjPcb, M3_Chip.SchDoc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]
2012-12-13 getting closer to synthesizing. For some reason message_fifo.v won't infer a ram block, so I have to switch to a dedicated ram.v block
    [basics_int.v, ice_bus_controller.v, priority_select.v]
2012-12-17 i2c sending working. Implementing this protocol is starting to make me want to cry
2012-12-18 works now, but think we might switch the meaning of fragment...
2012-12-21 well, didn't quite get the ICE board done, but found a cool chip to use and just some routing left...
    [FPGA_IO.SchDoc, M3 ICE.PcbDoc, M3 ICE.PrjPcb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]
2013-01-02 almost done w/ routing v1.1 board
    [FPGA_IO.SchDoc, M3 ICE.PcbDoc, M3.PcbLib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]
2013-01-02 board should be ready for fab now. Needs one last look-through.
    [FPGA_IO.SchDoc, FPGA_misc.SchDoc, M3 ICE.PcbDoc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]
2013-01-02 whoops, forgot to put the pull-downs on the m3 reg enable lines
    [FPGA_IO.SchDoc, M3 ICE.PcbDoc, M3.SchLib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]
2013-01-03 board submitted for fab
    [FPGA_IO.SchDoc, M3 ICE.PcbDoc, M3 ICE.PrjPcb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]
2013-01-12 adding new board to fix minor mistakes in v1.1...
    [FPGA_IO.SchDoc, FPGA_misc.SchDoc, M3 ICE.PcbDoc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]
2013-01-12 ugh, copied old files (not rev1.1)
    [FPGA_IO.SchDoc, FPGA_misc.SchDoc, M3 ICE.PcbDoc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]
2013-01-27 board ready for fab #2, fixing issues brought up by gyouho
    [FPGA_IO.SchDoc, M3 ICE.PcbDoc, M3 ICE.PrjPcb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]
2013-02-08 adding board v2.1 constraints folder, and some HDL that I forgot to commit earlier
2013-02-12 updated digikey part numbers
    [FPGA_IO.SchDoc, M3 ICE.PcbDoc, M3 ICE.PrjPcb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]
2013-04-19 fixed jumper issue
    [M3 ICE.PcbDoc, Power.SchDoc]
2013-07-16 adding third board design for mbus
    [FPGA_IO.SchDoc, FPGA_misc.SchDoc, M3 ICE.PcbDoc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]
2013-07-16 committing hdl for v1.2 board
2013-07-26 changing buffers and still in the process of making ICE board compatible with MBus
    [FPGA_IO.SchDoc, M3 ICE.PcbDoc, M3 ICE.PrjPcb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]
2013-07-29 done with schematic changes
    [FPGA_IO.SchDoc, M3 ICE.PcbDoc, M3 ICE.PrjPcb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]
2013-07-31 done with board. Needs schematic review and optional radio
    [FPGA_IO.SchDoc, M3 ICE.PcbDoc, M3 ICE.PrjPcb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]
2013-08-04 adding RF board which will be included on next ICE board
    [RF_board.PcbDoc, RF_board.PrjPCB, RF_board_rev3.PcbDoc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]
2013-08-06 added expansion header to ICE
    [FPGA_IO.SchDoc, M3 ICE.PcbDoc]
2013-10-07 adding ICE v2 schematics
2013-10-10 changing to FTDI chip for 3 Mbps
    [M3 ICE.PcbDoc, M3 ICE.PrjPcb, USB_to_UART.SchDoc]
2013-10-10 adding fab files used on most recent sunstone order
    [FPGA_misc.SchDoc, M3 ICE.PcbDoc, M3 ICE.PrjPcb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]
2013-10-24 adding constraints for v3 boards
2013-10-29 fixing conflicts in ice_bus
    [mbus_layer_wrapper_ice.v]
2013-10-30 couple small oops in last submit
2013-11-01 adding uart speed configuration command
2013-11-12 current project works as MBus slave
2013-11-17 adding SD for correct simulation
    [basics_int.v, gpio_int.v]
2013-11-18 fixing transition issues with pmu_int
    [mbus_layer_wrapper_ice.v, pmu_int.v, testbench.v]
2013-11-19 candidate fix to header_decoder to fix ein logic
    [testbench.v]
2013-11-19 lessened number of uart baud bits to make things fit onto FPGA
2013-12-10 fixed slight issue with capability query command
    [basics_int.v]
2013-12-14 fixing count for address sending with mbus
    [mbus_layer_wrapper_ice.v]
2013-12-14 asynchronous reset fixes to make things fit
    [basics_int.v, gpio_int.v]
2013-12-15 redefined MBus message format, added GPIO interrupt enable, redefined parameter fields for all GPIO messages
2013-12-15 Highlighting those mbus commands which are not supported by current mbus verilog
2013-12-18 adding new ICE board directory for larger FPGA
    [FPGA_IO.SchDoc, FPGA_misc.SchDoc, M3 ICE.PcbDoc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]
2014-01-31 fixing POR circuitry
2014-02-11 forgot to add new voltage domain for GOC light
2014-02-18 adding fiducials to ICE
    [FPGA_misc.SchDoc, M3 ICE.PcbDoc, M3 ICE.PrjPcb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]
2014-02-19 adding output job file to make my life easier in the future
    [M3 ICE.PcbDoc, M3.PcbLib]
2014-02-19 assembly package for Stephen Yun
2014-03-17 adding digireel part numbers
    [FPGA_IO.SchDoc, FPGA_misc.SchDoc, M3 ICE.PrjPcb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]
2014-04-17 adding board files for latest board run
2014-04-17 small changes to silkscreen - BOARD RUN
    [M3 ICE.PcbDoc]
2014-05-14 CHECKPOINT: candidate final design files for large-order ICE run
    [Power.SchDoc, RF_board.PcbDoc, RF_board.PrjPCB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]
2015-08-24 Prove strings convert to constants correctly
    [basics_int.v]
2015-08-28 Hold MBus in reset while FPGA is in reset
    Otherwise there is a window between FPGA de-asserting reset and
    the MBus module being reset where the MBus I/O lines are in a
    non-determinisitic state.
    [mbus_layer_wrapper_ice.v]
2015-08-29 Several testbench improvements
    * Modularize message sending so you can mix/match messages
    * Add support for sending messages to either ICE board in the loop
    * Wait for messages to finish rather than guess at delays
2015-08-30 fixing task syntax error in testbench.v
    [testbench.v]
2015-08-31 Add support for `ml` and `ms` messages
    I think there is still an issue with reporting the EoM and ack/nak
    bits correctly
    [basics_int.v, mbus_layer_wrapper_ice.v, testbench.v]
2015-08-31 Document additional bits the ICE board sets for `mB` messages
2015-09-15 Add explicit reset control
    [basics_int.v, testbench.v]
2015-11-24 candidate solution for uart rx issues
2015-12-10 appears that this was the actual UART issue. No hangups seen recently.
2016-01-06 adding schematics for v1.4 ICE board
2016-11-01 fixing BOM
    [M3 ICE.PrjPcb, rev1_4_bom.csv]
2017-05-10 Tests: added DMA write to memory
2017-05-15 UART: added error state
2017-05-15 UART: tweaks to make it pass up slow packets
2017-05-15 UART: tweaks to ice_bus for new 16 bit interface
2017-05-15 UART: default to 2MBaud, handle slow UART case gracefully
    UART: added error state
    UART: tweaks to make it pass up slow packets
    ICE: 2 MBaud
    UART: tweaks to ice_bus for new 16 bit interface
    UART: default to 2MBaud in v0.4
    [basics_int.v]
2017-06-20 TEST: added some basic unit testing
    Working MBUS_TX testcase
    TESTS: working on mbux_rx unit testing (broken currently)
    TESTS: mbux_rx now works
    TESTS: Added an mbus_ice_tx testcase
    [mbus_ice_tx_tests.v, mbus_rx_tx.v, mbus_tx.v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]
2017-06-20 ICE: Small Typo fixes
    [ice_bus_controller.v, mbus_layer_wrapper_ice.v]
2017-06-20 TESTS: working on a regression testing system
    TESTS: found testcase that will expose my bug
    [testbench.v]
2017-06-20 MUBS/BUG: mbus_tx bug fix with multi-word transmissions
    [mbus_layer_wrapper_ice.v, testbench.v]
2017-06-20 TESTS: added more regression testing
    TESTS: new test command sequence, overwrite short prefix to be 1 (i.e. CPU)
    TESTS: added a manual tx error mode
    TESTS: added some more glitch testing
    TESTS: tweaks for unit/regression tests
    [testbench.v]
2017-06-20 MBUS: ice state simplifications
    ICE_MBUS: removed an unnecessary state (hoping to solve a bug)
    ICE_MBUS: more state simplification
    [mbus_layer_wrapper_ice.v]
2017-06-20 ICE: removed a bunch of async resets, added syncro to ice_bus
    ICE_MBUS: removed async reset, glitchy?
    DBG: removed async reset from some more mbus stuff
    DBG: removed more async reset
    ICE: removed asynchronous resets throughout design, added synchronizer to ice_bus.v
    ICE: made mbus's reset synchroneous
    Conflicts:
    actel_proj/hdl_v4/ice_bus.v
    [basics_int.v, gpio_int.v]
2017-06-22 ICE: minor testcase tweaks and typo fixes
    TESTS: updated mbus tx tests
    ICE: fixed small compile typos
    [basics_int.v, mbus_ice_tx_tests.v, testbench.v]
2017-06-22 MBUS: rewrote TX and RX drivers, moved to seperate modules
    ICE_MBUS: rewrote tx state machine, moved to seperate module
    TESTS: new and improved ice mbus tx/rx testbench
    ICE_MBUS: working on RX driver
    ICE_MBUS: RX fixup
    actel_proj/hdl_v4/mbus_layer_wrapper_ice.v
    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
    [mbus_ice_driver_rx.v, mbus_ice_driver_tx.v, mbus_ice_tx_tests.v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]
2017-06-22 TESTS: correct timescales and delays for 20MHz
    [testbench.v]
2017-06-22 ICE: added top-level sync for reset
    ICE_BUS: moved the reset sync to the toplevel design
    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
    [testbench.v]
2017-06-22 ICE: synthesis warning fixes + fit in FPGA
    ICE: synthesis warning fixes
    ICE: shunk buffers to fit on FPGA
    actel_proj/hdl_v4/ice_bus_controller.v
    actel_proj/hdl_v4/pmu_int.v
    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
    [basics_int.v, gpio_int.v, ice_bus_controller.v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]
2017-06-23 ICE: minor testcase tweaks and typo fixes
    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
    [basics_int.v, mbus_ice_tx_tests.v, testbench.v]
2017-06-23 New MBUS TX/RX Drivers (#6)
    * ICE: minor testcase tweaks and typo fixes
    * MBUS: rewrote TX and RX drivers, moved to seperate modules
    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
    [mbus_ice_driver_rx.v, mbus_ice_driver_tx.v, mbus_ice_tx_tests.v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]
2017-06-23 ICE: Sync for Reset (#7)
    * TESTS: correct timescales and delays for 20MHz
    * ICE: added top-level sync for reset
    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
    [testbench.v]
2017-06-29 MBUS TX Bug Fixes (#9)
    * MBUS: double latched signals between clock domains (BUG FIX)
    [mbus_ice_driver_rx.v, mbus_ice_driver_tx.v, mbus_layer_wrapper_ice.v]
2017-07-01 Testcase that works with ACTEL toolchain (#14)
    * MBUS: converted file from DOS to UNIX format
    * ICE: reassigned GOC_PAD to output directly
    * TESTS: got testbench working with ACTEL
    actel_proj/hdl_v4/z_regression_tests/ice_startup_mbus_tx/testbench.v
    * fixup
    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
    [testbench.v]
2017-07-11 TESTS: new testbench to check power rails
2017-07-14 PMU: working on fixing PMU Read
    [pmu_int.v]
2018-01-12 TESTS: new testcase for PMU i2c interface
2018-01-12 PMU: fixes for PMU I2C interface, allow voltage reading
    [pmu_int.v]
2018-01-17 PMU: more i2c bugfixes
    [i2c_stub.v, pmu_int.v]
2018-01-17 PMU: fixed ICE response
    [pmu_int.v, testbench.v]
